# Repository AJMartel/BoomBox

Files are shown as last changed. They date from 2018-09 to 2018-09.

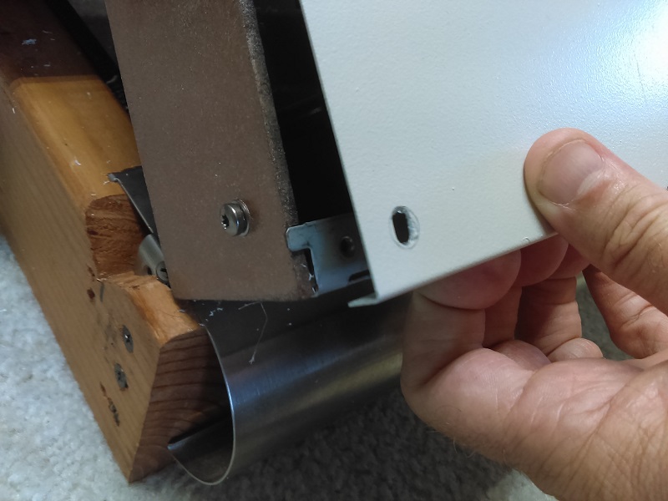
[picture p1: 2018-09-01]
IMAG0405.jpg

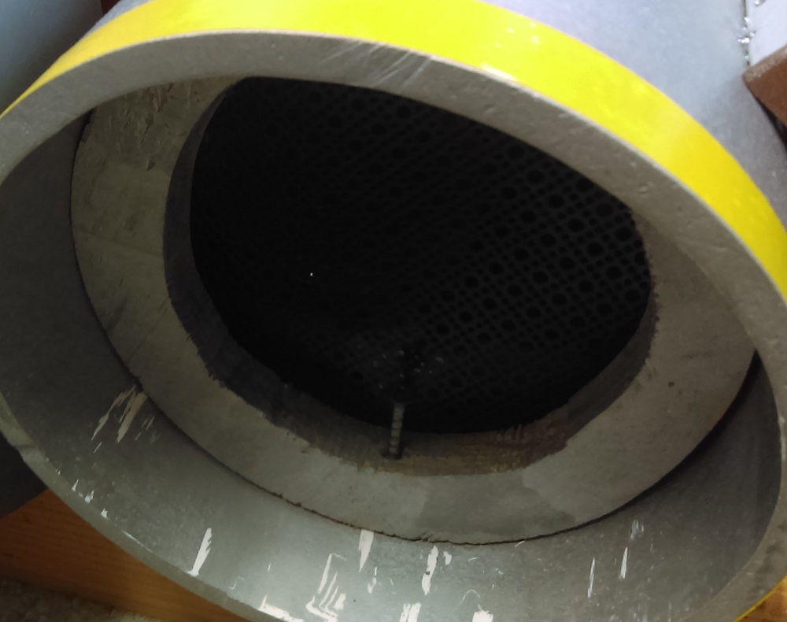
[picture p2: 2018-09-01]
IMAG0415.jpg

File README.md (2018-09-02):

# BoomBox
An airsoft game prop, featuring audio/mp3 capability, lighting, enhancement props, and bb air cannon.

There is no intent or schedule at this time to improve or build on this project, or make more versions. Its published here for a community share, more or less. I drew pretty heavily on posts and items others had shared when i built it, and thought i should give back.

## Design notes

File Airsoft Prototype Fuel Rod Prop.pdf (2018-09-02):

## Airsoft Prototype Fuel Rod Prop

The fuel rod prop is intended to assist airsoft games by adding a level of realism. It has 5 game modes, one demo mode and a sensitivity setting mode. The game mode is altered by simply tapping the device within 5 seconds of powering it up to step thru the modes.

It is a simple looking cylinder with 3 levels or RGB LED lights in the opaque center section. The main power switch is hidden in a pinhole and is a push-on/push-off style switch. The system takes input from a hidden internal magnetic switch in the rear of the base, and a shock sensing piezo. The system communicates its status using the RGB LEDs and a simple piezo beeper.

### Power

Power for the system is from an internal LiPo or NiMh (9.6v max power no matter what battery is used) battery connected with a deans connector. Changing the battery is as simple as unscrewing the lock screw and the end cap on the top of the device and switching out batteries.

### Setting a mode

Power on the device, using a pin or small metal rod to press the hidden power switch, then hold the device steady. The device will initialize and show the current mode. The mode is retained from the last setting automatically.

If you wish to change the mode, tap the device within 5 seconds of powering it on. Each tap will be reported by a change in the light display and the number of beeps corresponding to the mode. Since there is no other display, the RGB lights use binary to show the current mode (the top LED is bit 1, value of 1 - middle #2 LED is bit 2, Value of 2 - bottom #3 LED is bit 3, value of 4). You add up the lit lights to get the mode (mode 5 would be top and bottom or 1+4 lit up). Or just count the beeps.

### Charging Base

The unit uses a charging base with a hidden magnet to “charge” or “disarm” the device. The bases are not selective – all bases have the same effect, so it will be up to the players to follow rules about where they can charge and not “cheat”. However, players that figure out this fact may end up improving game play, so the enforcement of your rules on where and when a charge/discharge base can be used is entirely up to you.

One idea to enforce base restrictions is to mount the base on a removable stand, and place/remove the bases as needed for game play.

### Modes

The modes are as follows. More details about the mode are included below the table. Generally speaking, a blue unit is discharged and will not explode. A green unit is charged, and may or may not explode or discharge if shaken or the charge decays. Red is always danger. White indicates programming mode or what mode is selected.

Mode (binary) | Name | Details
1 (001) | Resupply Safe | Starts uncharged, so the players must find a base to charge it. After charged, the contents decay within 30 minutes. If a player

| | pushes the device into red mode by shaking it more than 5 times, the unit discharges.
2 (010) | Demo | Used in initial rally to show the players how the unit operates. Unit starts discharged, must be charged, then decays within one minute to “discharged” mode (blue). Unit can be recharged as many times as desired to demonstrate.
3 (011) | Sensitivity Set | Not a game mode. In this mode, the green LED blinks for 5 seconds waiting for you to “tap” the unit as hard as you want the shake sensor to be set. Hold the unit without shaking at all for maximum sensitivity, tap hard to make the unit robust. Hold unit still for 5 seconds to accept your setting after tapping.
4 (100) | Search & Rescue | Unit starts charged but “blinks” and beeps every 3 seconds to help locate it. Charge will decay within 30 minutes. The unit will go red if abused and pushed to red zone but will never explode or die from abuse. Game ends when charge totally decays, or they deliver it to a base and insert it to deliver the supplies.
5 (101) | Hot Potato | Unit starts charged. Pushing unit to red mode 5 times will cause it to explode. Unit will explode at the end of 30 minutes as well – UNLESS the base is used to reset the countdown.
6 (110) | Rush | Starts charged. Unit will react to shaking but will never be disabled. There is no decay, but the unit must be placed in a base for 5 minutes to explode. Unit resets after explosion.
7 (111) | Resupply Risky | Starts uncharged, so the players must find a base to charge it. After charged, the contents decay within 30 minutes. If a player pushes the device into red mode by shaking it more than 5 times, the unit explodes.

### Basic Diagram

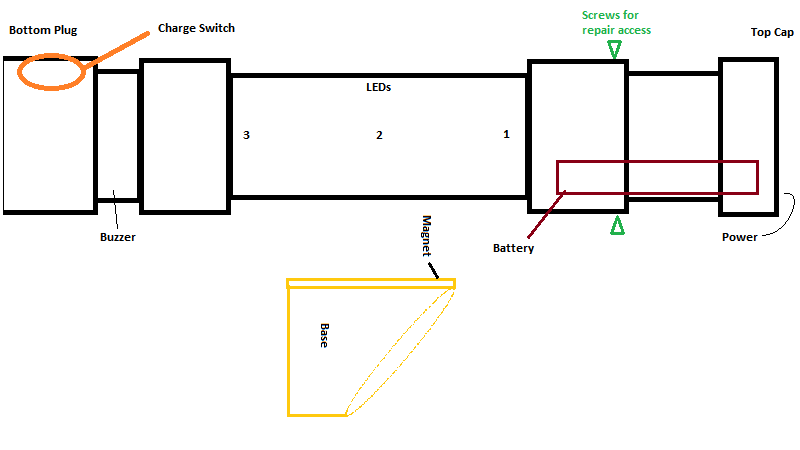
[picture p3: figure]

Cheat Sheet:

Mode (binary) | Name | Details
1 (001) | Resupply Safe | Uncharged, Charge decay 30m. 5Reds Discharges.
2 (010) | Demo | Used to demo unit. Starts discharged, once charged decays in 2 mins and shaking 2x makes it go red and discharge. Can be recharged.
3 (011) | Sensitivity Set | Unit blinks green for 5s listening for shake level (tap it how hard you want, not at all for max sense. Hold for 5s to accept level.
4 (100) | Search & Rescue | Blinks/beeps at start, picking it up starts 30m countdown to discharge. Charge decays in 30m. Insert in base to deliver and win.
5 (101) | Hot Potato | Charged. 5Reds to explode, or 30m countdown to explosion. Placing in base will reset countdown.
6 (110) | Rush | Charged, No shake reaction, no decay. Unit counts down 5m when placed in base to explosion, then resets.
7 (111) | Resupply Risky | Uncharged, Charge decay 30m. 5Reds Explodes.

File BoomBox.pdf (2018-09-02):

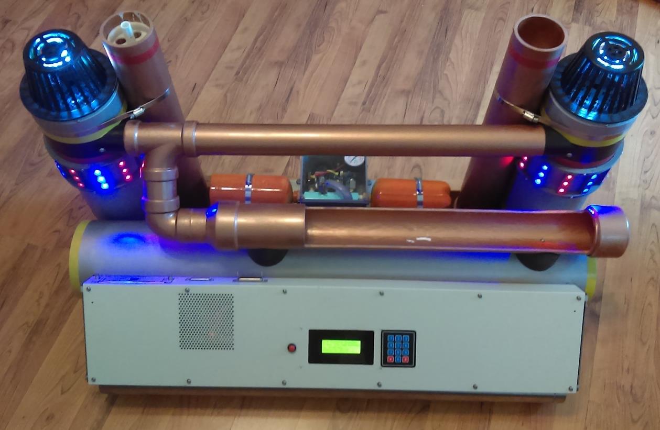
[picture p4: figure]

NOTICE – This *Manual* is part of a simulation designed for use by airsoft fields for entertainment and training purposes. No item described in this document is dangerous or life-threatening in the course of normal Airsoft Game Rules, and all organizations are fictitious. All trademarked names and logos and titles are owned by their respective copyright owners and all use is claimed as “fair use” for parody purposes.

# OPERATING MANUAL: BOOMBOX

DEVICE OVERVIEW

The following manual is intended for qualified personnel only. Operation and deployment of the BoomBox devices requires familiarity with the operating modes and options for maximum impact. Your effort in reviewing and practicing with the device, as well as anticipating how adept the players are at following the instructions, will be rewarded with smooth gameplay and maximum player involvement.

What follows is the operation and maintenance guide for this particular model: The BOOMBOX model.

CONTENTS

NORMAL OPERATION PROCEDURES

MODES OF OPERATION

The unit supports four modes of operation:

1. Simple Countdown Timer to Detonation
2. PIN code Lockdown to Detonation
3. Repeating Countdown to Detonation
4. Nuclear Fuel Charge and Countdown

Mode 4 assumes that a compatible Fuel Rod device is available. Modes can be altered or the device reset using the Initial Configuration process detailed below.

NOTE THAT IF A SYSTEM RESET IS NOT PERFORMED ON POWER-UP, THE LAST OPERATING MODE IS RE-STARTED.

STRONG RF EMISSIONS NEAR THE DEVICE HAVE BEEN PROVEN TO CAUSE UNDESIRED OPERATION, INCLUDING HANGING THE CONTROLLER, ERRONEOUS KEYPAD ENTRY, ETC. IT IS RECCOMMENDED THAT RF TRANSMITTERS ARE NOT OPERATED WITHIN SEVERAL FEET OF THE DEVICE.

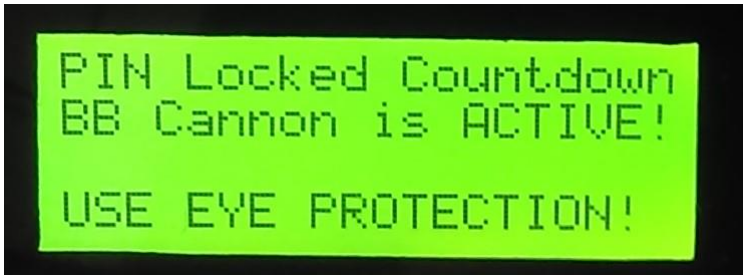
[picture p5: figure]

WARNING. IF THE BB CANNON IS ENABLED, THE SYSTEM WILL PLAY AN ALERT AT THE BEGINNING OF THE GAME. NO WARNING IS GIVEN BEFORE THE BB CANNON FIRES. THE COMPRESSOR WILL NOT RUN IF THE BB CANNON IS DISABLED HOWEVER, SO THAT IS THE BEST INDICATION DURING GAME PLAY THAT THE CANNON WILL FIRE UPON DETONATION. THE COMPRESSOR POWERS UP 30 SECONDS BEFORE DETONATION.

INITIAL CONFIGURATION/RECONFIGURATION

Initial configuration or altering the system settings is performed by accessing the programming menu. Since timing is critical, please read this section entirely before proceeding.

Follow these steps to initialize the device:

1. Obtain a thunder-B pin or other suitable small metal pin to use as the power key.
2. Note the position of the key access hole. Press a pin into the hole to turn the unit on and off.

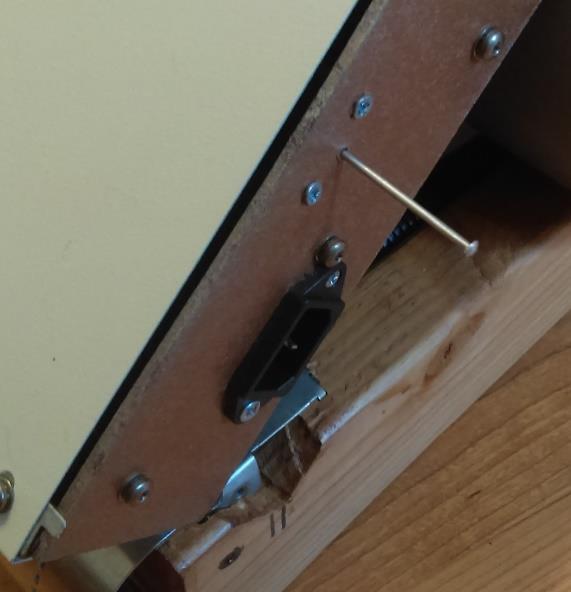
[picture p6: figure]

3. Once powered up, the system start initialization. Lights and audio effects will begin. Once the LCD initializes, important information will be displayed, including warnings about battery life. If no other option is chosen the device will immediately start the last configured game mode.
4. Immediately press and hold the red button to reset the device.
5. The device will reset the memory and allow you to select the mode of operation.

Preparing the BB Cannon is a simple matter of filling it with BBs from the top of the tube. It doesn’t matter if you fill the center or main fill holes around the center barrel, either will work. Not all BBs will be used in every shot, however the design is tolerant of some stray debris. Using ‘used’ bbs is permitted assuming they are not overly dirty. If the BB pressure setting needs to be adjusted the pressure switch can be adjusted by removing the cover and adjusting the screw (in means less pressure, 10-70PSI range). The duration of the pump power is controlled by the program and is not programmable.

PROGRAMMING MENU DETAILS

The following settings are available in Program Mode. Most of the features affect multiple game modes, but some have different effects depending on Game Mode. For example, EOD Mode allows guessing a PIN on PIN game, but in Fuel Charge mode it allows bypassing the detonation by simply holding a button. Details on modes and flow of the game is described in the game mode sections below.

1. Game Mode Selection:
a. Countdown Timer to Detonation
b. PIN code Lockdown to Detonation
c. Repeating Countdown to Detonation
d. Nuclear Fuel Charge and Countdown

2. Pre-Countdown Locate Beep: Prior to starting a countdown, the device can “beep” every 3 seconds to aid players in locating it. This mode allows you to hide the device on the field and help players find it easier.
3. Countdown Strobe: Enable or disable the strobe to flash every second during an active countdown.
4. Countdown Beep: Enable or disable the beeper to sound every second during an active countdown.
5. Countdown Time: Countdowns can run from 1 minute to 1000 minutes.
6. EOD Mode: Explosive Ordinance Disarming Expert Mode enable or disable. In PIN game, EOD means guessing a PIN will tell you high/low and never detonate from a bad PIN. In Nuclear Canister mode, the system can be disarmed by holding the red button for 2 minutes without interruption. Note that this mode is SEPARATE from the card/canister disable option.
7. Canister Sense: Allows using a suitable fuel rod to disarm the device instead of a card.
8. Card Sense: Enabling this mode allows a “hacking card” to immediately disable the device during countdown.
9. PIN: Enter a 1-9 digit PIN. If EOD mode is enabled, a 4 digit PIN should be used at the minimum.
10. Two Minute Warning: Enable this to hear the 2 minute klaxon sound and voice warning.
11. Two Minute Song: The MP3 song number to play as a two minute ambient music selection. MP3 song numbers can be found in the hidden MP3 Jukebox mode. (Ask)
12. Alert Duration: Number of seconds (1-240) that the alarm sounds when the device is detonated.
13. BB Cannon: Enable or Disable the BB Cannon when the device is detonated. Note that the compressor will also start ~30 seconds before end of countdown if BB Cannon is enabled.
14. MP3 Juke Box Mode: Set this to O to disable, or number of minutes between songs (5 or more suggested) if you want the device to randomly choose an MP3 song to play after being disabled or detonated.
15. Main Volume: Volume level (1-30) of most announcements. Warnings and effects may be louder than this level and cannot be adjusted. During MP3 play, the 7 and * keys allow volume up/down adjustments independent of the main volume setting.

FUEL ROD INTEGRATION NOTE

The Fuel Rod Prop suggested game play mode is any mode that uses the base to discharge the fuel rod. At the current time, that is:

- Mode 1 – Hot Potato
- Mode 5 – Search and Rescue

The fuel rods or canisters must have a strong magnet to trigger the sensor in the bottom left canister slot (over the left support). A small strong magnet is embedded in the bottom of the canister slot to trigger Fuel Rod sensors as well.

MODE 1 - SIMPLE COUNTDOWN TIMER TO DETONATION

Mode 1 allows the typical scenario – Once you start the countdown, it continues until the device detonates. You can pause the countdown by pressing the red button. You can also disable the device by using the card or fuel canister, if you have enabled those options.

Note that if you enable the card defeat or canister option, those devices must NOT be present or installed when the countdown starts (or it would immediately end). Of course, it is possible to put a dummy card or fuel rod in the device, which does not have the magnets installed, in order to allow normal operation.

EOD mode does not have any effect on this game mode.

GAME FLOW

The initial flow of this game, from system power on, is as follows:

1. System Powers up. Self-checks for battery level and other items are made, and warnings are played if the BB cannon is enabled.
2. Self-checks for cards or canisters are made if those options are enabled, and the system will wait until those are removed before proceeding.
3. The device will wait until a red button is pressed to begin the countdown. If the locator option is enabled, it will also beep once every 3 seconds to aid players in locating it. Once players start the countdown the locator will stop.
4. The device will count down to detonation:
a. If the two minute warning option is enabled, a two minute alert klaxon sound and voice will be heard just before 2 minutes.
b. If the two minute ambient music option is set to a song number other than 0, that song will be played. Recommendation is to play track 36, which ends exactly at 2 minutes.
c. If the BB Cannon is enabled, at 30 seconds the compressor will start up and pump up the chambers.
5. Detonation can be disabled by inserting a bypass “hacking” card, or inserting a canister, assuming those options are enabled in programming (card sense, and can sense).
6. The countdown can be “paused” by pressing the red button. Pressing the red button again restarts from the same point in the countdown.
7. At detonation the device will sound for the set alert period and stop.
8. After detonation, the device will wait the number of minutes (0 disables) and randomly play an MP3 file. Red button stops the song, 7 and * keys adjust volume up and down.

MODE 2 – PIN CODE LOCKDOWN TO DETONATION

Mode 2 allows the device to be locked down using a 1-9 digit PIN code. The device can be unlocked by entering the same code again.

NOTE – ENTERING AN INVALID PIN CODE 4 TIMES WILL INVOKE THE “ANTI-HACKING” MODE, CAUSING THE DEVICE TO DETONATE AND REMOVE SAID HACKERS.

EOD Mode allows an EOD expert to bypass the countdown by guessing the PIN code. In EOD mode, the system will allow unlimited PIN guesses without detonating. Each guess will trigger a “too high” or “too low” response, allowing the player to adjust their next guess. With a 4 digit PIN above 1000, this can take on average 2 minutes to guess.

Hitting the * key gives a -/+ 200 numbers range on the display. This quickly reduces the guessing time. Tell players about this hint if you wish.

Hacking cards and canisters will disable the system immediately if those options are enabled.

GAME FLOW

The initial flow of this game, from system power on, is as follows:

1. System Powers up. Self-checks for battery level and other items are made, and warnings are played if the BB cannon is enabled.
2. Self-checks for cards are made if those options are enabled, and the system will wait until those are removed before proceeding.
3. The device pauses and waits for the proper PIN code. The countdown will not start without the PIN code. (EOD guess mode is not enabled for the initial starting PIN.)
4. Once the PIN is entered the countdown begins. The countdown may be halted by one of the following methods:
a. Entering the PIN again pauses the countdown.
b. Guessing the PIN with EOD Mode enabled pauses the countdown.
c. Entering the wrong PIN 4 times WITHOUT EOD Mode detonates the device.
d. Inserting a “hacking card” with card sense enabled disables the device.
e. Inserting a fuel rod with “can sense” enabled disables the device.
5. If the device is disabled, the countdown cannot be restarted. If the device is paused using the correct PIN, the countdown may be continued by entering the correct PIN again.
6. The device will count down to detonation:
a. If the two minute warning option is enabled, a two minute alert klaxon sound and voice will be heard just before 2 minutes.
b. If the two minute ambient music option is set to a song number other than 0, that song will be played. Recommendation is to play track 36, which ends exactly at 2 minutes.
c. If the BB Cannon is enabled, at 30 seconds the compressor will start up and pump up the chambers.

7. At detonation the device will sound for the set alert period and stop.
8. After detonation, the device will wait the number of minutes (0 disables) and randomly play an MP3 file. Red button stops the song, 7 and * keys adjust volume up and down.

MODE 3 – REPEATING COUNTDOWN TO DETONATION

Mode 3 allows a somewhat modified scenario – Once you start the countdown, it continues until the device detonates and cannot be paused. You can “reset” the countdown by pressing the red button, which causes the countdown to restart from the beginning. You can also disable the device by using the card or fuel canister, if you have enabled those options. Without the disable card or canister, the device can never be disabled, and must constantly be reset to prevent detonation.

Note that if you enable the card defeat or canister option, those devices must NOT be present or installed when the countdown starts (or it would immediately end). Of course, it is possible to put a dummy card or fuel rod in the device, which does not have the magnets installed, in order to allow normal operation.

EOD mode does not have any effect on this game mode.

GAME FLOW

The initial flow of this game, from system power on, is as follows:

1. System Powers up. Self-checks for battery level and other items are made, and warnings are played if the BB cannon is enabled.
2. Self-checks for cards or canisters are made if those options are enabled, and the system will wait until those are removed before proceeding.
3. The device will wait until a red button is pressed to begin the countdown. If the locator option is enabled, it will also beep once every 3 seconds to aid players in locating it. Once players start the countdown the locator will stop.
4. The device will count down to detonation:
a. If the two minute warning option is enabled, a two minute alert klaxon sound and voice will be heard just before 2 minutes.
b. If the two minute ambient music option is set to a song number other than 0, that song will be played. Recommendation is to play track 36, which ends exactly at 2 minutes.
c. If the BB Cannon is enabled, at 30 seconds the compressor will start up and pump up the chambers.
5. Detonation can be disabled by inserting a bypass “hacking” card, or inserting a canister, assuming those options are enabled in programming (card sense, and can sense).
6. The countdown can be “reset” and forced to restart the countdown from the beginning by pressing the red button.
7. At detonation the device will sound for the set alert period and stop.

8. After detonation, the device will wait the number of minutes (0 disables) and randomly play an MP3 file. Red button stops the song, 7 and * keys adjust volume up and down.

MODE 4 – NUCLEAR FUEL CHARGE AND COUNTDOWN

This mode allows the charging and arming of the device using a suitable Nuclear Fuel Rod/canister. You should start this mode with the canister REMOVED. You can give the canister to the players or make them find it. Once the nuclear fuel charge is loaded, a countdown begins. The countdown can be cancelled by attaching a suitable canister and transferring the charge back.

NOTE – THE FUEL ROD CANISTER MUST HAVE THE REQUIRED MAGNETS AND COMPONENTS IN ORDER TO WORK WITH THIS MODE. JUST ANY CYLINDER WILL NOT WORK!

EOD Mode allows an EOD expert to bypass the countdown by holding the red button for 4 minutes.

Canisters will not “disable” the system countdown immediately, but are used in a “discharge” sequence and end up disabling the countdown eventually. Hacking cards will disable the system immediately if that option is enabled.

GAME FLOW

The initial flow of this game, from system power on, is as follows:

1. System Powers up. Self-checks for battery level and other items are made, and warnings are played if the BB cannon is enabled.
2. Self-checks for cards are made if those options are enabled, and the system will wait until those are removed before proceeding.
3. The canister must be removed from the device and the red button pressed to set the unit up for game play. THIS IS DONE BY THE ADMIN. Once this is done, the device is ready to accept a canister from a player to start the arming sequence. You don’t have to have the canister to start this mode, but if you do, and it’s present on the device, you do have to remove it to start the game mode.
4. The device asks the player to insert the canister, which starts the prime process. This process takes 10 seconds.
5. The device asks the player to hold the red button to charge the device. This takes 10 seconds.
6. The device asks the player to remove the canister to start the countdown.
7. Once removed, the countdown starts.
8. The device will count down to detonation:
a. If the two minute warning option is enabled, a two minute alert klaxon sound and voice will be heard just before 2 minutes.
b. If the two minute ambient music option is set to a song number other than 0, that song will be played. Recommendation is to play track 36, which ends exactly at 2 minutes.

c. If the BB Cannon is enabled, at 30 seconds the compressor will start up and pump up the chambers.
9. Detonation can be disabled by inserting a bypass “hacking” card (card sense must be enabled), or inserting a canister and following the discharge process. EOD mode allows disabling the device by holding the red button for 4 minutes continuously.
10. If the EOD mode is not enabled, and the red button is pressed in an attempt to bypass the device but a fuel rod is NOT present, a hacking attempt is triggered and an accelerated countdown begins.
11. At detonation the device will sound for the set alert period and stop.
12. After detonation, the device will wait the number of minutes (0 disables) and randomly play an MP3 file. Red button stops the song, 7 and * keys adjust volume up and down.

SYSTEM MAINTENANCE

OVERVIEW

System maintenance includes items such as pre-operation checks, battery charging and replacement, and fuse replacement. The system is generally built to handle normal use but any time the device is dropped, kicked or knocked over, an inspection of the internal connections and components should be performed.

Modifying the code operation – aside from the configuration options in the programming menu – is not covered in this manual. The unit uses C++ Arduino style programming language with a Teensy 3.2 LC controller and a DFRobot MP3 player device, and does support direct USB connections for reprogramming. Please contact the D14 owners for questions about the program source code or design documentation.

TROUBLESHOOTING STRANGE BEHAVIOR

Note that if a program mode is NOT performed on power-up, the last operating mode is re-started.

Strong RF emissions near the device have been proven to cause undesired operation, including hanging the controller, erroneous keypad entry, etc. It is recommended that RF transmitters are NOT operated within several feet of the device.

If the device display becomes garbled or appears to hang, power the system down with the access key, then power it back on. The last program will be restarted.

If the strobes or air horn devices sound continuously, the MOSFET devices may have failed. MOSFET devices typically (eventually) fail as a short circuit. Turn off the controller with the key switch, and remove the right access panel to access the main system fuses, or disconnect the battery from the control or compressor or other components. Pulling fuses is recommended.

In the event of continuous air horn operation, use hearing protection when trying to disable the system. Do not attempt to disable to compressor or horns directly, rather, remove power from the compressor by disabling main power or removing the fuse.

OPENING THE CASE

The case should be opened using the round screen panel on the right side of the main tube body (when facing the keypad). Phillips head screws can be unscrewed half-way and the cover removed. Once that is accomplished, the internal component board can be pulled out to the right for service.

Note that to reinstall the main power board, you must also remove the left cover and guide the power board into the correct position, under the holding tab.

ALWAYS DISCONNECT ONE OR BOTH OF THE MAIN BATTERY CONNECTORS WHEN PERFORMING SERVICE.

MOSFETS AND SEVERAL COMPONENTS ARE ‘GROUND-SWITCHED’. WHICH MEANS THEY RECEIVE CONSTANT POWER FROM THE BATTERY + RAIL, AND GROUND IS SWITCHED BY THE MOSFET DEVICES. THIS MEANS THE MOSFET TABS AND HEAT-SINKS WILL NORMALLY BE RESTING AT +12VDC DURING OPERATION.

ACCESSING THE POWER BOARD COMPONENTS

1. Using a phillips screw driver, unscrew the 3 screws on the right tube cover. If you only unscrew them half-way you should be able to use them to pull the cover out.
2. Remove the cover, exposing the internal carrier board and connectors. Space is tight, so use a flashlight to look into the tube and slide the board out, rotating if needed to clear the cable feeds coming in the top of the tube. Gently slide out the borad half-way, then unplug the connectors if you intend to completely remove it. If you only need fuse access you don’t need to slide it out further. If you need to change the battery you should remove the entire board.
3. Details on the internal components and a component list is available in the specifications section of this document.
4. Reinstalling the board requires you to remove the left cover. Slide the board thru the tube until it reaches the tang that holds it down on the left. Move the metal tang around until it will slide over the board.
5. Push the board in the rest of the way until it bottoms out on the left holder. The board should be level, resting on the screw on the left (prevents it from rotating counterclockwise).
6. Push the right cover in and drive the screw in thru the tube and into the mounting wood base.

ACCESSING THE CONTROL PANEL INTERIOR

1. Using a suitable Torx bit, unscrew the 12 screws on the top and bottom of the front cover.

2. Remove the card from the top left of the control box.

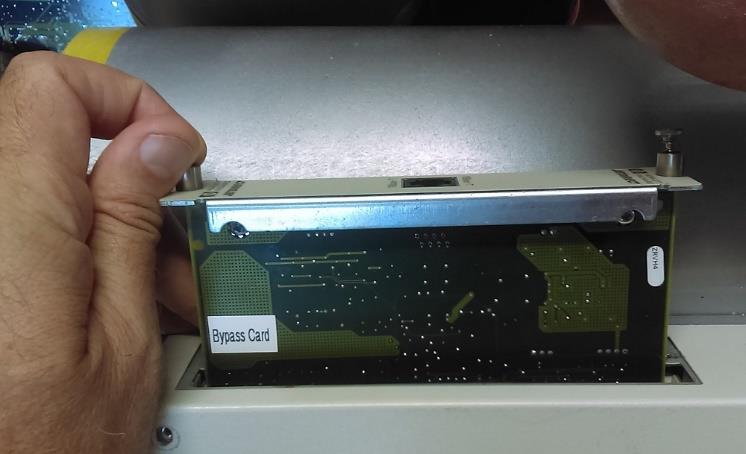
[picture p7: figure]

3. From the bottom, gently lift the front cover up:

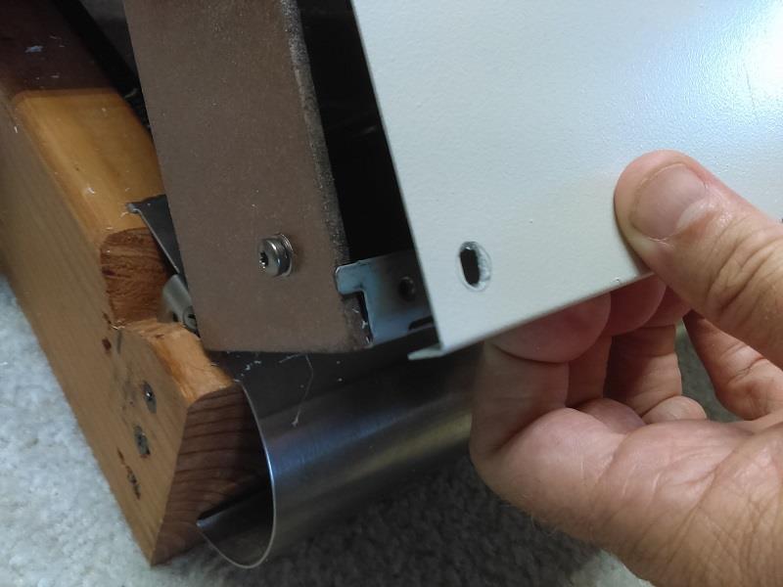
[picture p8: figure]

4. Slide the cover up to clear the connectors on top of the box, but DO NOT move the cover too far away from the unit, as you need to disconnect the LCD button and keypad.

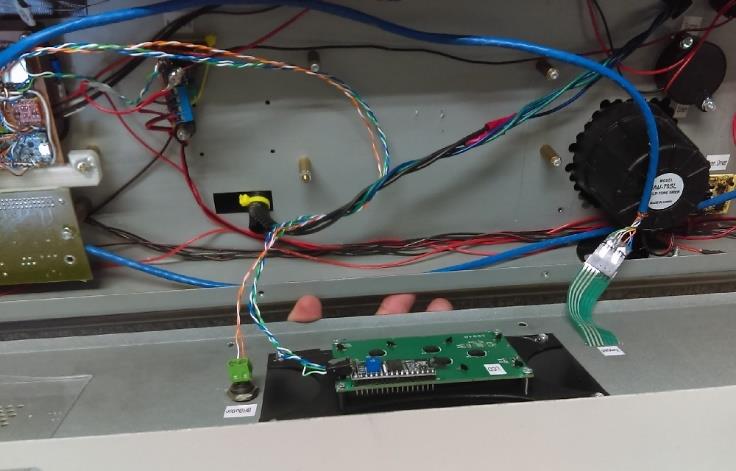
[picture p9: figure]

5. It is possible to rest the cover against the front of the unit without disconnecting cables.

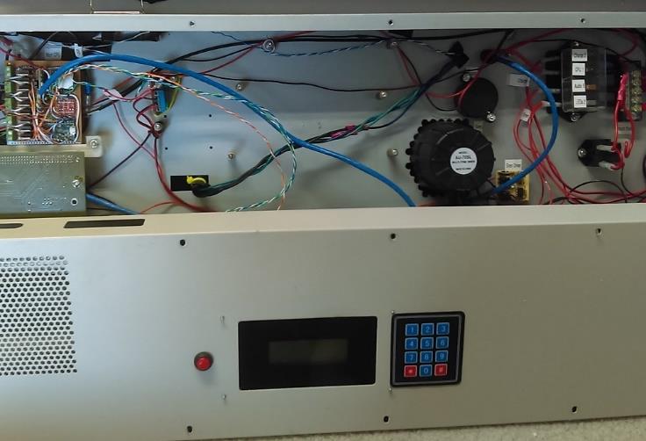
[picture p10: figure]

6. Details on the internal components and a component list is available in the specifications section of this document.

BATTERY CHARGING

Connect a business power cord to the right end of the control box, and plus the other end into a typical 120VAC US outlet. The on-board SLA battery charger may take several hours due to battery capacity (it is a larger 8A-Hr SLA). Battery is considered charged when the voltage reaches 13.6 VDC. Battery voltage less than 10.5V is not recommended and can damage the SLA battery.

NOTE – THE INTERNAL CHARGER IS INTELLIGENT, AND WILL SWITCH TO FLOAT MODE AUTOMATICALLY. THE DEVICE CAN BE LEFT PLUGGED IN INDEFINITELY WITHOUT CAUSING BATTERY DAMAGE.

Any white crusty residue on the “top” of the battery, or swelling of the battery indicates internal failure and requires the battery to be disposed of immediately. A Sulphur or rotten-egg smell also indicates overcharging and possible battery damage.

BATTERY REPLACEMENT

As this unit uses a Sealed Lead Acid Battery (SLA), please replace the battery with a suitable sized replacement. SLA batteries can be mounted in any position. The existing cell is a 7 or 8 Amp-Hour 12V battery. Power is marked as Red for +12V, and black for Ground.

Unscrew the bracket holding the battery down and one or more of the side screws to free the battery. When tightening the new battery down, ensure there is a very small amount of “wiggle-room” so the plastic battery case is not being crimped. Overtightening can crack the new battery case.

This is a standard battery design, and any battery with similar specifications can be used – whether it was sold for UPS, deer-feeder, telecom, or general use.

As the battery uses lead, proper disposal should be performed. Do not discard the battery in normal trash. Dispose of or recycle according to local ordinances.

FUSE REPLACEMENT

Fuses should not typically blow unless an internal short develops in the device or a component. Before replacing a fuse, investigate the component that blew the fuse and verify it is not malfunctioning. If the main 30A fuse blows, disconnect all other fuses (and keep track of which wires go with which fuse) and reconnect components one fuse at a time to isolate the cause.

Component | Fuse Size | Purpose
Main Battery 30 | 30A | Main power for all systems.
Air Horn 25 | 25A | Power for the Air Horn compressor (high current!)
Compressor 7.5 | 7.5 | Power for the air compressor for BB Cannon.
Valve/Relay 5 | 5A | Power for the Air valve and Relays.
Smoke 10 | 10A | Power for an optional component, originally intended for Smoke.
Control Box 10 | 10A | Power for the microcontroller, display, LED, Sound.
Charge 2 | 2A | Safety fuse for the power from the battery charger, to the power board.
CPU1 | 1A | Power for the Arduino and MP3 device board.
Audio5 | 5A | Power for the Audio Amp.
LEDs2 | 2A | Power for LED Strobe lights.

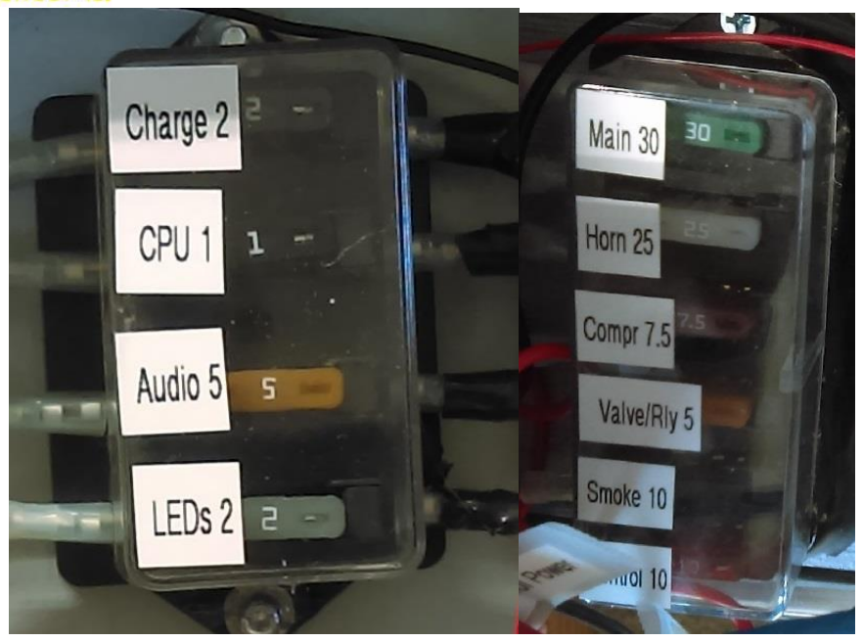
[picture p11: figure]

AUXILLARY INFORMATION/SPECIFICATIONS

INTERNAL COMPONENT LIST

The following components are used in this device.

Component

Main Battery. SLA 12VDC 7 or 8 AHr battery. (UB1280 or similar) 30A Main fuse on battery.

Power board Fused power connection block. Most high power component fuses are located here.

Ground Distribution bank. Used to ground various parts of the system.

Relay bank. Clamping Diode installed across coils of each relay. If you replace this device use a suitable clamping diode to shunt spikes and connect with correct polarity. Relay is 30A, 30VDC rated. 12V coil. Relays are labeled for purpose. Equipment is ground switched or positive switched depending on system. Relay coils are ground switched.

Air horn compressor. Loud on its own, bolted to the carrier board. Uses a 20A fuse. No maintenance possible on this part.

Air Horns. Dual low frequency horns, zip-tied for convenient removal/replacement.

Deans connectors – connecting compressor, main control box power, and main power.

Cat5 Network connection. Used to run relay control wires from control board.

Keypad/Control box. Teensy 3.2 LC controller with custom program, keypad and LCD I2C interface, MP3 serial interface and power regulation as well as control MOSFET switches are located on the control board to the left. On-board MP3 player uses a micro SD card to store sounds and audio. MP3 amplifier is near main control board. Siren driver board is next to the siren. Beeper is above the siren. Control system fuses and 120VAC battery charger. Main power switch turns on the 30A relay in the control box to power up control electronics and LED/audio.

LCD display – I2C connected to CPU board, blue, 4x20characters.

“Red Button” – main button used to arm/disarm/enter reset mode. Hold this button when powering system up to reset the device.

Power Switch. Switches power to control box only – however this will generally turn off all components. The charger will operate regardless of system power switch state.

Keypad – a standard 3x4 numeric keypad.

LED rings – Blue and RED alternating LED displays.

Speaker tubes – Speakers are outdoor rated and waterproof but may not survive if water is left standing on the speakers. If rain is encountered, cover the unit and tilt over to ensure no water collects in speakers or tubes.

White LED strobes – located above speakers.

BB Cannon tube – a simple air powered device. Air fires from the bottom bb reservoir across a small gap into the main tube. BBs are sucked up into the air flow and out the unit. Any BBs can be used, as long as they are not too dirty.

Air Valve – a sprinkler valve located under the unit to release air on command by the CPU.

Compressor box – houses a small 12VDC car compressor, limit switch (50PSI) and safety valve plus a gauge. Do not block the inlet or outlet near tanks.

Air tanks – repurposed propane tanks (cleaned), with no neck valves. Tank safety valve is retained but should never be used as the safety limit valve is set to a much lower 100PSI level and should always release first.

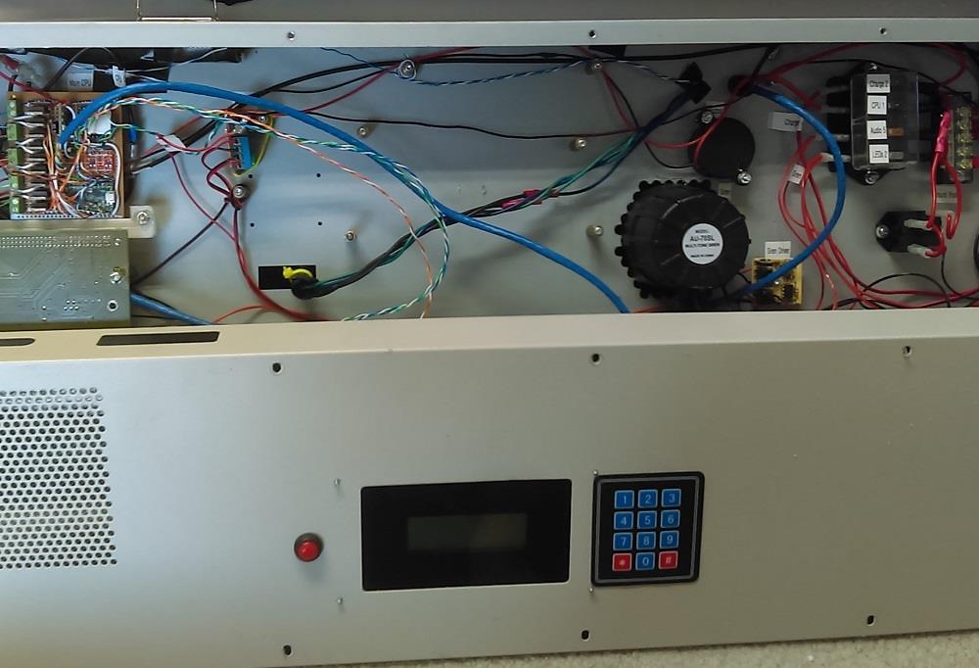
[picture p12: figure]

Internal Components: Control Box:

Main CPU Board

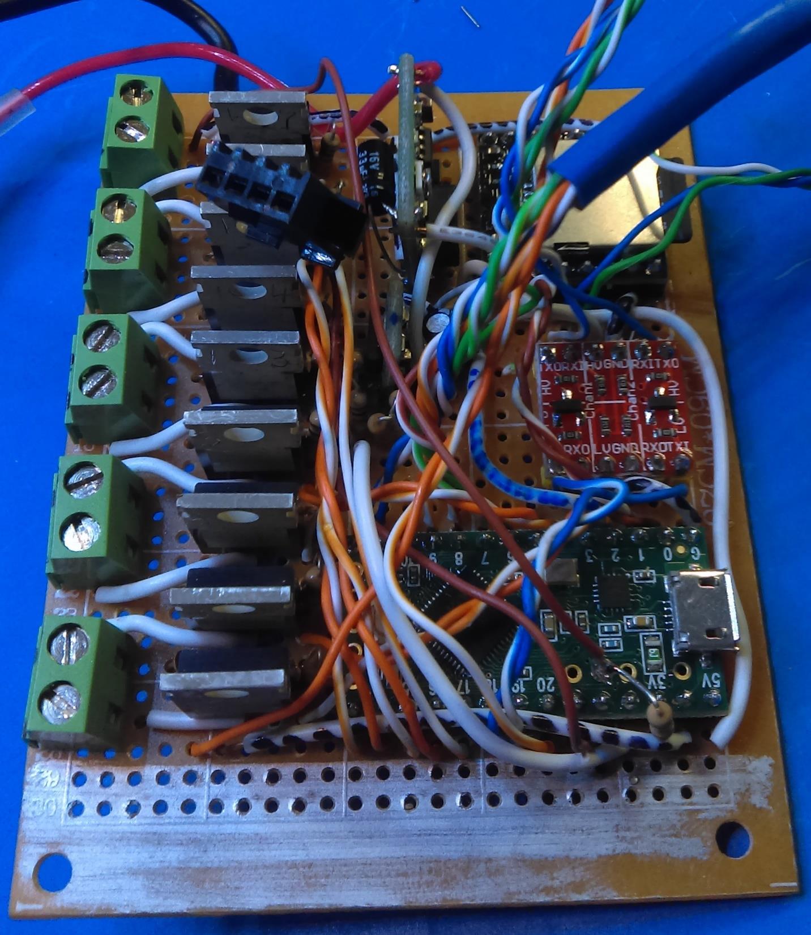
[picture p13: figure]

Mai n
Main CPU board, with Teensy 3.2 LC at the bottom, level adapter above that, MP3 DF Robot board (with SD Card) above that. The center contains a 5V regulator (do not adjust!) and 3.3v regulator board, both mounted on end. The left side contains 9 channels of MOSFET drivers with screw down terminals. Cables run to can and card sense connectors, BRB connections, LCD connections, MP3 connections and Keypad connections as well as power and ground. Since the unit switches ground to devices, the ground lead is much larger than the power lead.

Compressor Box:

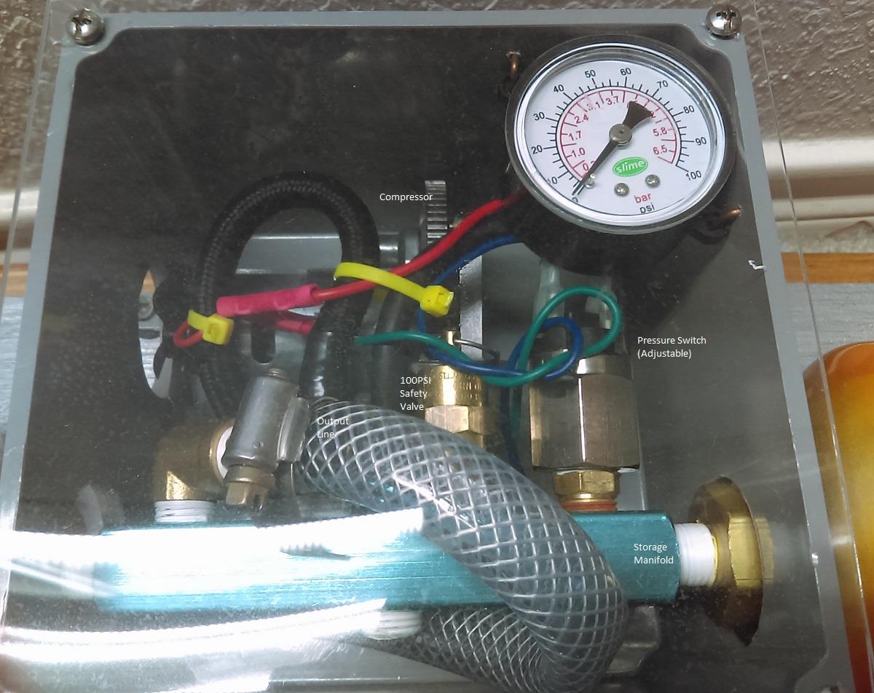
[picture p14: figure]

Compressor, Pressure Switch (50PSI setting, adjustable), safety valve (100PSI), gauge, manifold to tanks. Tanks are cleaned recycled Propane canisters, so some odor is present (it is not dangerous). There is also a sprinkler valve under the main tube and pipe to the (left) bb Cannon tube.

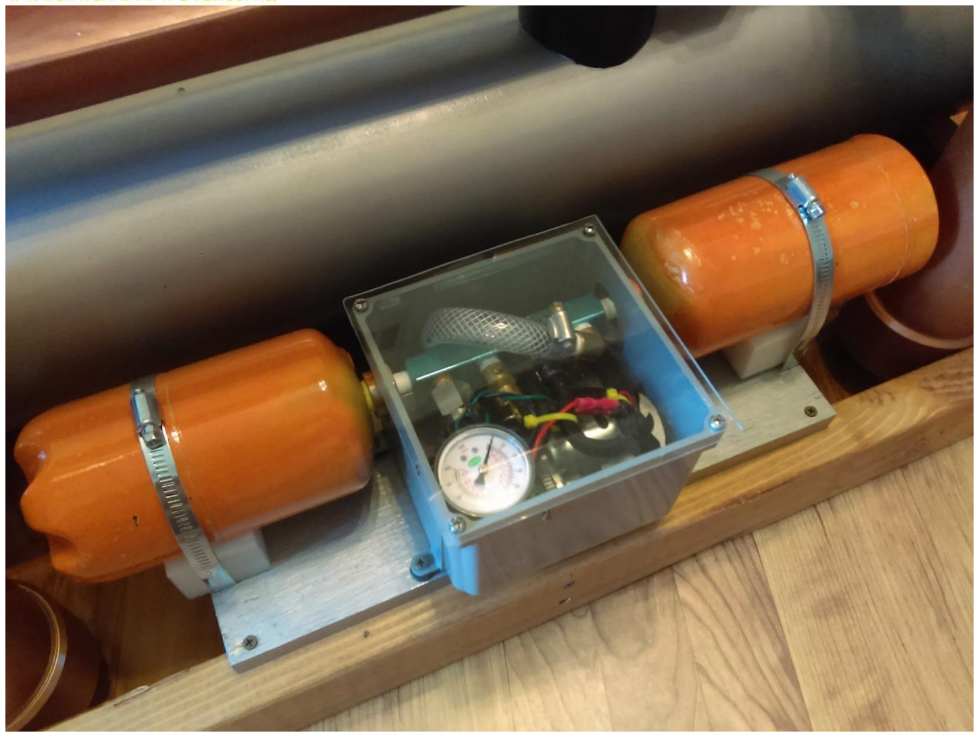
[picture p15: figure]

Power Board: Fuses and Relays

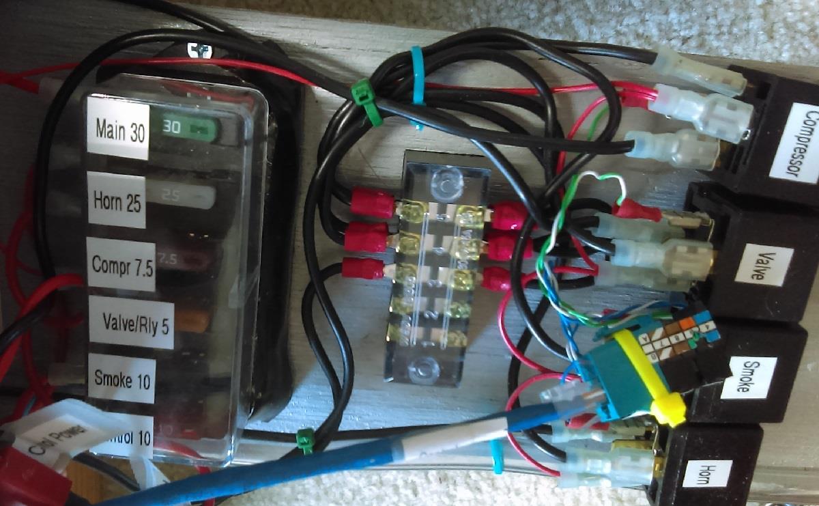
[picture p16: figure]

Fuses for major systems, ground supply block, relay bank and control cable connection are shown.

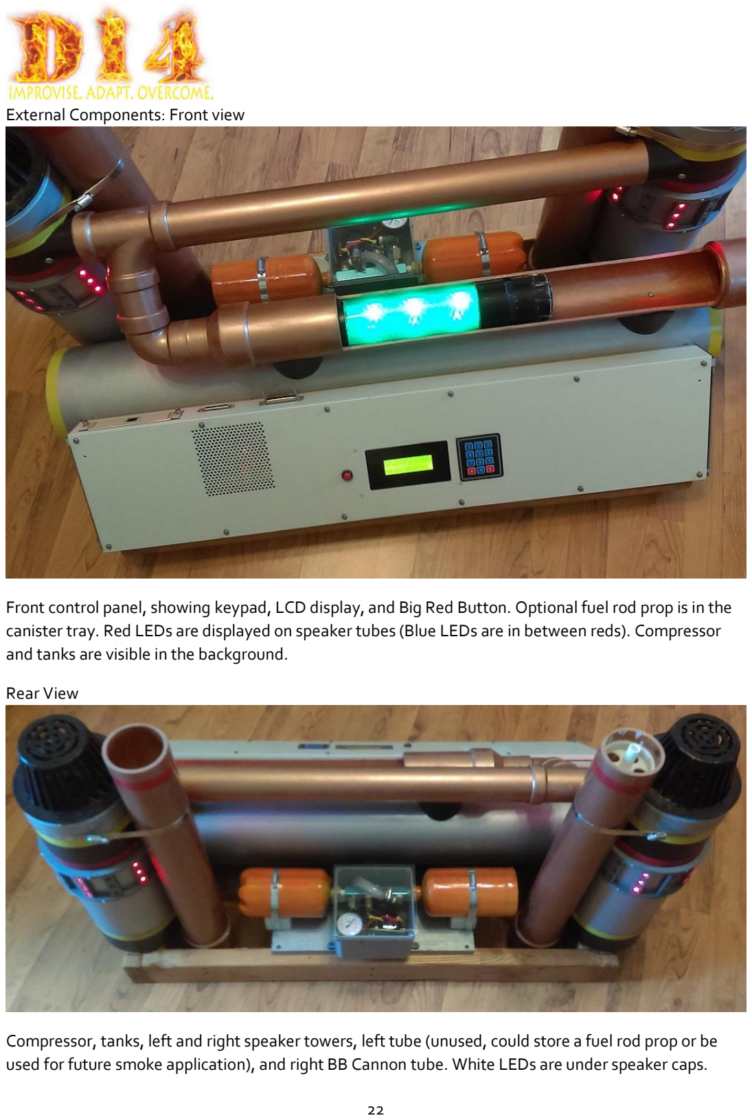
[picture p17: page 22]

External Components: Front view

Front control panel, showing keypad, LCD display, and Big Red Button. Optional fuel rod prop is in the canister tray. Red LEDs are displayed on speaker tubes (Blue LEDs are in between reds). Compressor and tanks are visible in the background.

Rear View

Compressor, tanks, left and right speaker towers, left tube (unused, could store a fuel rod prop or be used for future smoke application), and right BB Cannon tube. White LEDs are under speaker caps.

Miscellaneous Specs:

Weight: 28 Kg or 62 lbs.

Width: 1.17M 46 in.

Depth: 0.56M or 22 in.

Height: 0.69M or 27 in.

Power Supply: Internal 12VDC SLA battery, 7AHr.

Power Draw: Detonated – 23A Max, intermittent. 1A Idle. 2A countdown w/strobes, intermittent.

Theoretical Battery Life – 8Ahr/(1A average)=8 hours? Exact time estimates depend heavily on options chosen and volume of MP3 audio system.
Date of Creation: August 31st, 2016.

Paint Codes: RUST-OLEUM Hammered spray paints, Silver 7213, Copper 210849

Teensy LC Pinout:

Pin | Mode | Description
RX1,TX1 | Dig I/O | MP3 (DFRobot) Serial control.
D2 | Dig Out | Siren Out to MOSFET.
D3 | Dig Out | Compressor Out to MOSFET.
D4 | Dig Out | Air Valve Out to MOSFET.
D5 | Dig Out | Buzzer Out to MOSFET.
D6-D12 | Dig In | Keypad input Pin6-9: R1-R4, Pin 10-12: C1-C3
D13 | Dig Out | RED LED Out to MOSFET.
D14 | Dig Out | BLUE LED Out to MOSFET.
D15 | Dig Out | WHITE LED Out to MOSFET.
D16 | Dig Out | Smoke Out to MOSFET. (not enabled, for expansion)
D17 | Dig Out | Air Horns Out to MOSFET.
SDA0, SCL0 | Dig I/O | 3.3v I2C to level shifter, to LCD.
D20 | Dig In | Big Red Button input.
D22 | Dig In | Canister/Fuel Rod sense input.
A9 | Analog In | Battery Volt Sense, through divider (6.8K over 1.2K).
D24 | Dig In | Card sense input.

Fuel Rod/Canister modification: The fuel rods or canisters must have a strong magnet to trigger the sensor in the bottom left canister slot (over the left support). A small strong magnet is embedded in the bottom of the canister slot to trigger Fuel Rod sensors as well.

Schematic:

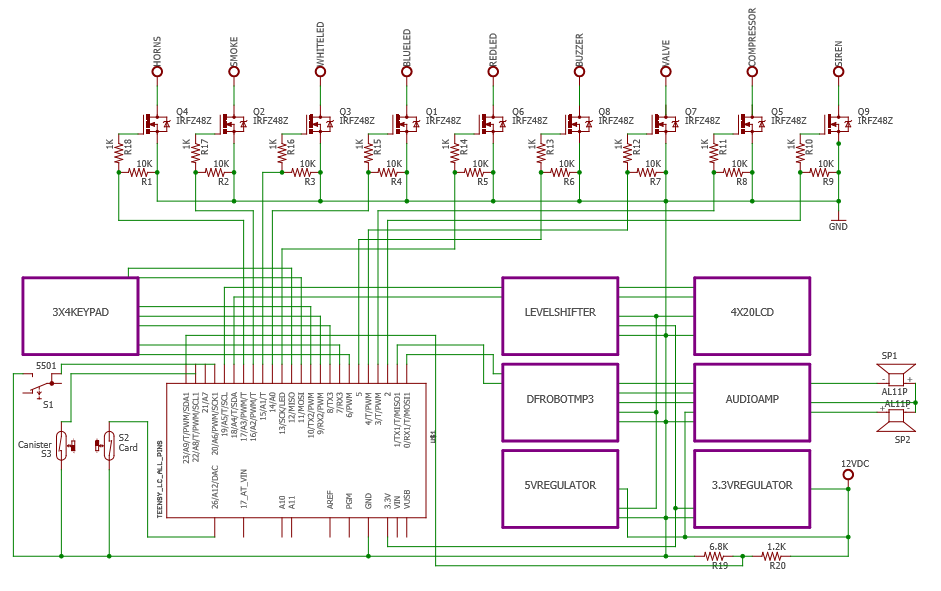
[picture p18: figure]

QUICK REFERENCE SHEET

Print copies of the following sheet for in-field reference.

Program Mode: Hold red button while turning device on with key switch. Wait for “Programming Mode” to be displayed or announced before releasing button.

Program Selection: The following program options are available.

1. Game Mode Selection:
a. Countdown Timer to Detonation
b. PIN code Lockdown to Detonation
c. Repeating Countdown to Detonation
d. Nuclear Fuel Charge and Countdown
2. Pre-Countdown Locate Beep: Prior to starting a countdown, the device can “beep” every 3 seconds to aid players in locating it. This mode allows you to hide the device on the field and help players find it easier.
3. Countdown Strobe: Enable or disable the strobe to flash every second during an active countdown.
4. Countdown Beep: Enable or disable the beeper to sound every second during an active countdown.
5. Countdown Time: Countdowns can run from 1 minute to 1000 minutes.
6. EOD Mode: Explosive Ordinance Disarming Expert Mode enable or disable. In PIN game, EOD means guessing a PIN will tell you high/low and never detonate from a bad PIN. In Nuclear Canister mode, the system can be disarmed by holding the red button for 2 minutes without interruption. Note that this mode is SEPARATE from the card disable option.
7. Canister Sense: Allows using a suitable fuel rod to disarm the device instead of a card.
8. Card Sense: Enabling this mode allows a “hacking card” to immediately disable the device during countdown.
9. PIN: Enter a 1-9 digit PIN. If EOD mode is enabled, a 4 digit PIN should be used at the minimum.
10. Two Minute Warning: Enable this to hear the 2 minute klaxon sound and voice warning.
11. Two Minute Song: The MP3 song number to play as a two minute ambient music selection. MP3 song numbers can be found in the hidden MP3 Jukebox mode. (Ask)
12. Alert Duration: Number of seconds (1-240) that the alarm sounds when the device is detonated.
13. BB Cannon: Enable or Disable the BB Cannon when the device is detonated. Note that the compressor will also start ~30 seconds before end of countdown if BB Cannon is enabled.
14. MP3 Juke Box Mode: Set this to O to disable, or number of minutes between songs (5 or more suggested) if you want the device to randomly choose an MP3 song to play after being disabled or detonated.
15. Main Volume: Volume level (1-30) of most announcements. Warnings and effects may be louder than this level and cannot be adjusted. During MP3 play, the 7 and * keys allow volume up/down adjustments independent of the main volume setting.

DISCLAIMER AND WARNINGS

This device is designed to enhance game play in an Airsoft scenario game. It is not dangerous or life threatening, assuming normal Airsoft game play rules are followed. Following typical rules, especially eye protection, when the BB Cannon is enabled should protect players from injury. The device is not intended to be moved during game play, especially by less than 2 people. Always instruct players to keep clear of the BB Cannon at all times, regardless of whether the system is powered or armed. When not in use, cover the cannon to prevent debris from entering or protect if accidental discharge occurs.

While it should be readily apparent to anyone this is a prop, based on design, it is still prudent to cover and conceal the device from general public view when not in use on the playing field.

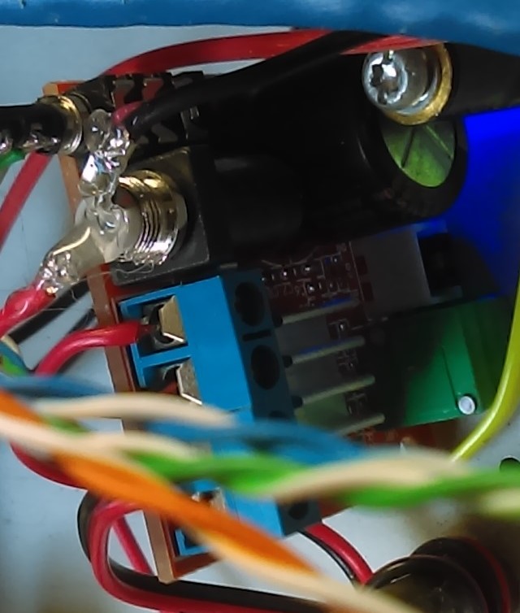
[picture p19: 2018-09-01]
IMAG0412.jpg

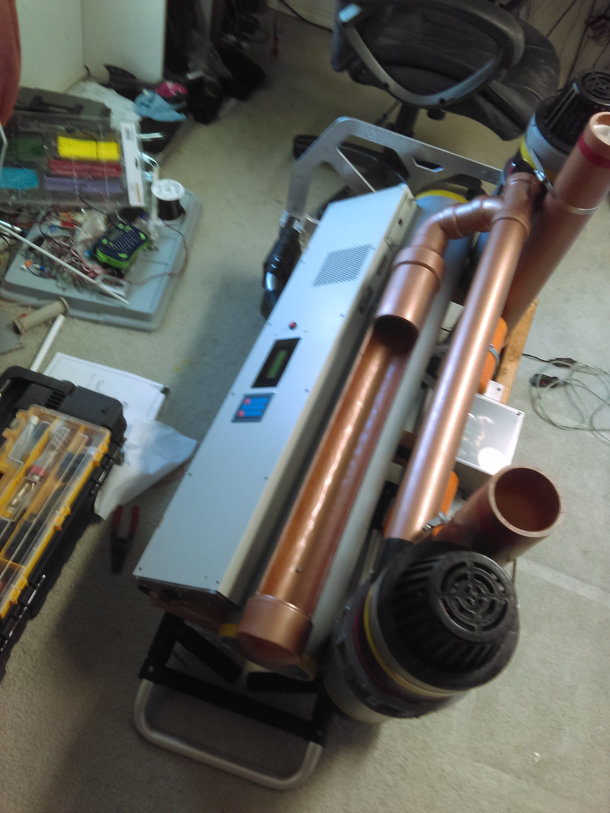
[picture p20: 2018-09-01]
IMAG0398.jpg

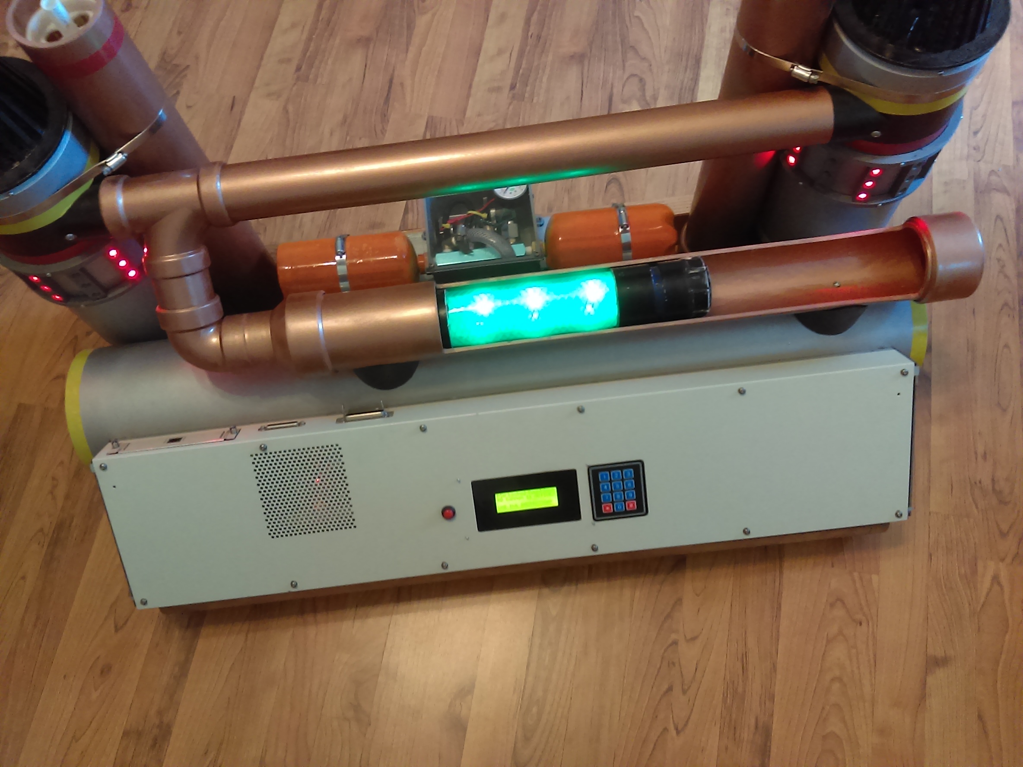
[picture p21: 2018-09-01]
IMAG0432.jpg

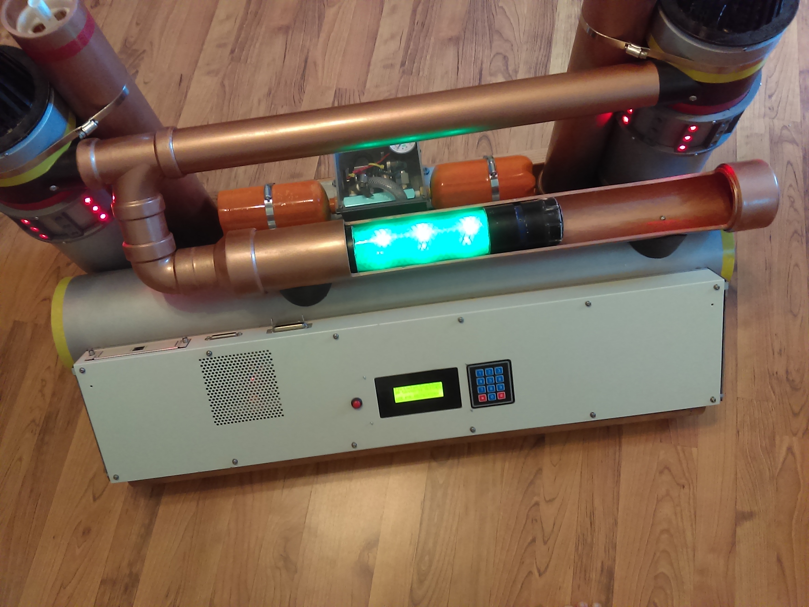
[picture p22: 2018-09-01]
IMAG0434.jpg

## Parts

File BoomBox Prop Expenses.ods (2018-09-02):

Item | SubComponent | Base Price | Qty | Amount | Taxable | With Tax | Tax Rate
3D Printed LCD Holder | Control Box | $- | 1 | $- |  | $- | $0.08
All external wood treated or painted. | Appearance | $- |  | $- |  | $- | $0.08
All PVC externals sanded and painted and routed for joints to appear smoother. | Appearance | $- |  | $- |  | $- | $0.08
All wire connectios soldered and shrunk or crimped, if not part of a connector. | Misc | $- |  | $- |  | $- | $0.08
Code Dev Time-Hours (actual * .3 factor for my non-expert skills? No idea what value is...) | Code | $- | 40 | $- |  | $- | $0.08
Code for Fuel Rod (added BoomBox Mode) | Control Box | $- |  | $- |  | $- | $0.08
Documentation. | Code | $- |  | $- |  | $- | $0.08
Misc Paint (Orange, Black, Hammered Copper, Silver) | Appearance | $- | 1 | $- |  | $- | $0.08
SamCobalt Bar Magnets (Fuel Rod Mod) | Control Box | $0.25 | 1 | $0.25 |  | $0.25 | $0.08
1x4"x4' Plywood mounting board | Power Board | $0.50 | 1 | $0.50 |  | $0.50 | $0.08
Reed Switch (Canister Sense) | Control Box | $0.50 | 1 | $0.50 |  | $0.50 | $0.08
SamCobalt Round Magnets (Fuel Rod Trip) | Control Box | $0.25 | 3 | $0.75 |  | $0.75 | $0.08
1/2 NPT Plugs | BB Shower | $0.90 | 1 | $0.90 |  | $0.90 | $0.08
Heat Shrink (1/2*2in, 1/4*4in) | Misc | $0.25 | 4 | $1.00 |  | $1.00 | $0.08
Solder | Misc | $1.00 | 1 | $1.00 |  | $1.00 | $0.08
3/4 to 1/2 Barb right angles | BB Shower | $1.20 | 1 | $1.20 |  | $1.20 | $0.08
Crimps | Misc | $0.12 | 10 | $1.23 |  | $1.23 | $0.08
TTL Level Converter | Control Box | $1.67 | 1 | $1.67 |  | $1.67 | $0.08
5V (adjustable) regulator | Control Box | $1.82 | 1 | $1.82 |  | $1.82 | $0.08
3D Print power adapter | Control Box | $2.00 | 1 | $2.00 |  | $2.00 | $0.08
3D printer tank holders | BB Shower | $1.00 | 2 | $2.00 |  | $2.00 | $0.08
End cap covers (circle wood) | Power Board | $1.00 | 2 | $2.00 |  | $2.00 | $0.08
End cap covers (rect wood) | Control Box | $1.00 | 2 | $2.00 |  | $2.00 | $0.08
Split Loom (6 ft of 18) | Appearance | $6.20 | 0.3 | $1.86 | 1 | $2.01 | $0.08
PEX tube | BB Shower | $1.86 | 1 | $1.86 | 1 | $2.01 | $0.08
Silicone Black | Audio System | $3.94 | 0.5 | $1.97 | 1 | $2.13 | $0.08
White LED Module | Audio System | $1.00 | 2 | $2.00 | 1 | $2.17 | $0.08
Cantex 4x4x2 box | BB Cannon | $6.88 | 0.3 | $2.06 | 1 | $2.23 | $0.08
10 ga Solid Wire ($/ft) | Power Board, Control Box | $0.20 | 12 | $2.40 |  | $2.40 | $0.08
Perfboard | Control Box | $2.49 | 1 | $2.49 |  | $2.49 | $0.08
3D Printed BB Canon Parts | BB Cannon | $5.00 | 0.5 | $2.50 |  | $2.50 | $0.08
Zip Ties | Misc | $0.10 | 25 | $2.50 |  | $2.50 | $0.08
Manifold | BB Cannon | $5.37 | 0.5 | $2.69 |  | $2.69 | $0.08
2x4x12 | Appearance | $2.65 | 1 | $2.65 | 1 | $2.87 | $0.08
Keypad | Control Box | $2.99 | 1 | $2.99 |  | $2.99 | $0.08
PC-XT power plug/socket (2pack) | Control Box | $5.98 | 0.5 | $2.99 |  | $2.99 | $0.08
Pushbutton Switch | Control Box | $2.99 | 1 | $2.99 |  | $2.99 | $0.08
I1N4454 Diodes | Power Board | $0.60 | 5 | $3.00 |  | $3.00 | $0.08
Blue LED Module (10 of 20pack) | Audio System | $6.99 | 0.5 | $3.50 |  | $3.50 | $0.08
Red LED Module (10 of 20pack) | Audio System | $6.99 | 0.5 | $3.50 |  | $3.50 | $0.08
3" Branch Adapter | Appearance | $3.48 | 1 | $3.48 | 1 | $3.77 | $0.08
3.3V regulator | Control Box | $3.79 | 1 | $3.79 |  | $3.79 | $0.08
3" to 4" adapter PVC | Appearance | $3.74 | 1 | $3.74 | 1 | $4.05 | $0.08
DFRobot MP3 Module | Audio System | $4.22 | 1 | $4.22 |  | $4.22 | $0.08
Barrel Power Connector | Audio System | $3.99 | 1 | $3.99 | 1 | $4.32 | $0.08
Mini Pushbutton Switch (power) | Control Box | $3.99 | 1 | $3.99 | 1 | $4.32 | $0.08
Propane Tanks (modified, painted) | BB Cannon | $3.99 | 1 | $3.99 | 1 | $4.32 | $0.08
Ground Dist Block | Power Board, Control Box | $4.47 | 1 | $4.47 |  | $4.47 | $0.08
12V Buzzer | Control Box | $4.72 | 1 | $4.72 |  | $4.72 | $0.08
Bussman Low Amp Fuse Pack | Control Box | $4.39 | 1 | $4.39 | 1 | $4.75 | $0.08
1/8 Audio Jack | Audio System | $4.49 | 1 | $4.49 | 1 | $4.86 | $0.08
3D Printed LED rings | Audio System | $2.50 | 2 | $5.00 |  | $5.00 | $0.08
Cat5 Connector and Plug | Power Board | $5.00 | 1 | $5.00 |  | $5.00 | $0.08
Staineless Steel Front Cover | Appearance | $5.00 | 1 | $5.00 |  | $5.00 | $0.08
Black Ornate Screen Aluminum Milled Sheet (end covers) | Power Board | $18.98 | 0.25 | $4.75 | 1 | $5.14 | $0.08
Misc Connection Wire | Control Box, Power Board | $5.00 | 1 | $5.00 | 1 | $5.41 | $0.08
32GB SD Card | Audio System | $5.45 | 1 | $5.45 |  | $5.45 | $0.08
Colored Vinyl Tape | Appearance | $5.67 | 1 | $5.67 |  | $5.67 | $0.08
3" right angle PVC | Appearance | $2.65 | 2 | $5.30 | 1 | $5.74 | $0.08
Resistors (10k*2, 220*2, 1m) | Control Box | $0.25 | 23 | $5.75 |  | $5.75 | $0.08
Nuts & Bolts | Misc | $5.90 | 1 | $5.90 |  | $5.90 | $0.08
4" PVC end cap | Appearance, BB Shower | $2.10 | 3 | $6.30 | 1 | $6.82 | $0.08
1.2 NPT to 1/2 barb | BB Shower | $3.19 | 2 | $6.38 | 1 | $6.91 | $0.08
Plexiglass sheet (Comp cover, CPU cover, LCD Cover) | BB Cannon, Control Box | $7.99 | 0.8 | $6.39 | 1 | $6.92 | $0.08
4 Fuse Power Dist Block | Control Box | $6.99 | 1 | $6.99 |  | $6.99 | $0.08
Vinyl Flex Pipe | BB Cannon | $6.60 | 1 | $6.60 | 1 | $7.14 | $0.08
Steel Band Clamp 4" | Appearance, BB Shower, Power Board | $1.68 | 4 | $6.72 | 1 | $7.27 | $0.08
Screw Connectors | Control Box | $1.50 | 5 | $7.50 |  | $7.50 | $0.08
IRFZ34 MOSFET N channel | Control Box | $0.88 | 9 | $7.94 |  | $7.94 | $0.08
LCD 4x20 + I2C interface | Control Box | $8.55 | 1 | $8.55 |  | $8.55 | $0.08
100PSI Safety Valve | BB Shower | $8.61 | 1 | $8.61 |  | $8.61 | $0.08
6 Fuse Power Dist Block | Power Board | $8.69 | 1 | $8.69 |  | $8.69 | $0.08
1/8 to 1/4 NPT adapter | BB Shower | $8.90 | 1 | $8.90 |  | $8.90 | $0.08
HP JetDirect Cards (2 modified for disable) | Control Box | $3.00 | 3 | $9.00 |  | $9.00 | $0.08
4" x 10' PVC DVW tube | Appearance | $12.17 | 0.7 | $8.52 | 1 | $9.22 | $0.08
10x2W Audio Amp | Audio System | $9.88 | 1 | $9.88 |  | $9.88 | $0.08
Control Box | Control Box | $10.00 | 1 | $10.00 |  | $10.00 | $0.08
Adjustable NC Pressure Switch | BB Shower | $10.49 | 1 | $10.49 |  | $10.49 | $0.08
Smart SLA Charger | Control Box | $10.99 | 1 | $10.99 |  | $10.99 | $0.08
Landscape Drain Heads | Audio System | $5.38 | 2 | $10.76 | 1 | $11.65 | $0.08
3" x 10' PVC DVW tube | Appearance, BB Shower | $10.78 | 1 | $10.78 | 1 | $11.67 | $0.08
12VDC Siren | Audio System | $11.77 | 1 | $11.77 |  | $11.77 | $0.08
30A 12VDC Relay | Control Box, Power Board | $2.50 | 5 | $12.50 |  | $12.50 | $0.08
12V Slime Brand Car Compressor | BB Shower | $12.28 | 1 | $12.28 | 1 | $13.29 | $0.08
Sprinkler Valve | BB Cannon | $12.97 | 1 | $12.97 | 1 | $14.04 | $0.08
Propane to 1/2NPT adapter | BB Shower | $7.58 | 2 | $15.16 |  | $15.16 | $0.08
Pyle PLMR51B Speakers | Audio System | $20.39 | 1 | $20.39 |  | $20.39 | $0.08
12v SLA 7Ahr | Power Board | $19.99 | 1 | $19.99 | 1 | $21.64 | $0.08
Teensy 3.2 LC | Control Box | $19.99 | 1 | $19.99 | 1 | $21.64 | $0.08
Steel Band Clamp 6" | Appearance, BB Shower | $4.36 | 5 | $21.80 | 1 | $23.60 | $0.08
Dual Horn Air Horn | Audio System | $35.00 | 1 | $35.00 | 1 | $37.89 | $0.08
 |  |  |  | $512.68 |  | $532.48

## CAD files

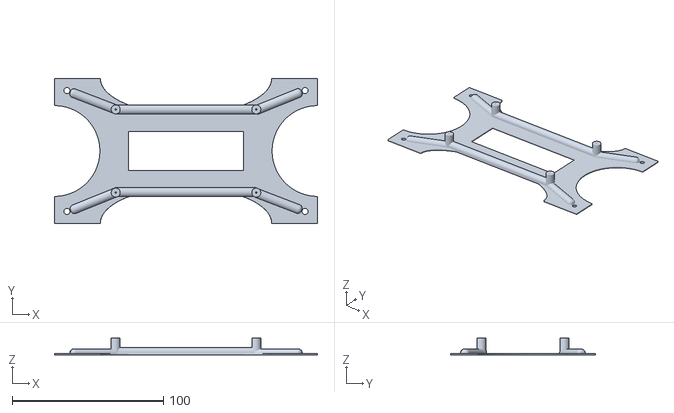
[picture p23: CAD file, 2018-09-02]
Huge Prop Bomb LCD.stl
174.0 x 96.0 x 11.0

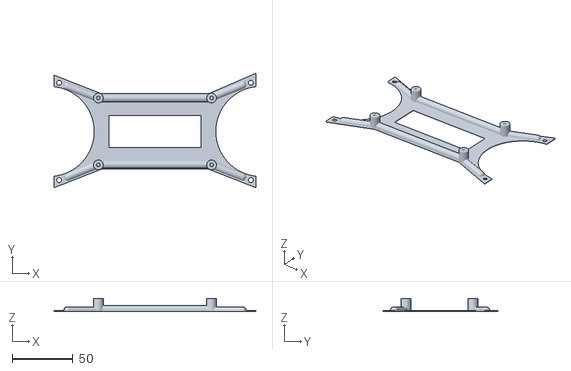
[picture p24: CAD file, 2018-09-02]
BB LCD b.stl
166.0 x 94.2 x 11.0

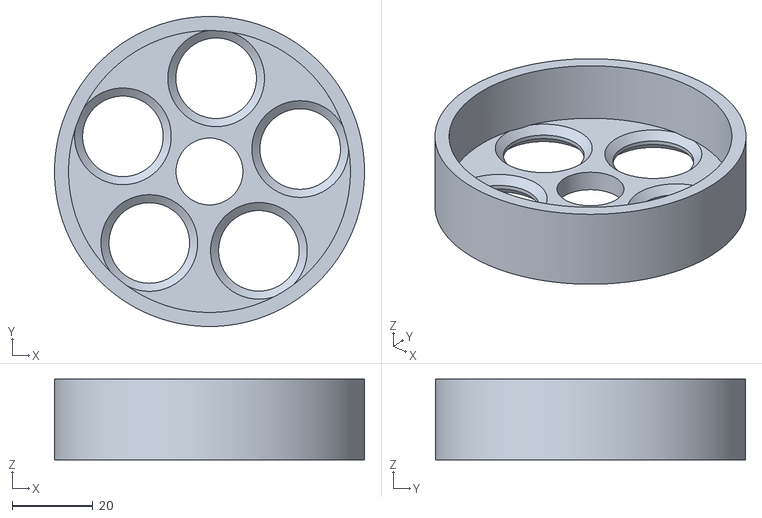
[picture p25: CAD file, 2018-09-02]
BB Shower Support.stl
77.0 x 77.0 x 20.0

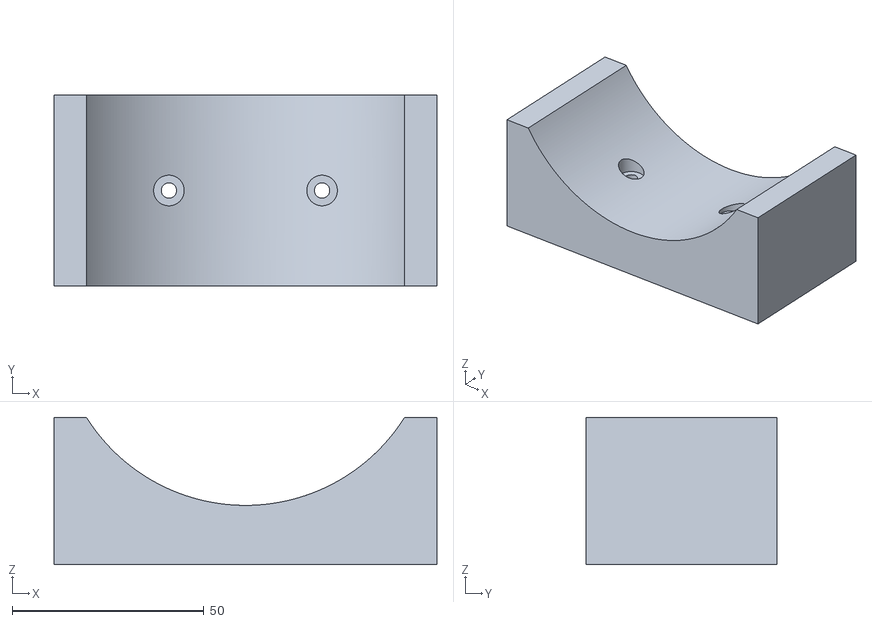
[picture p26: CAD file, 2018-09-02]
Huge Prop Bomb Tank.stl
100.0 x 50.0 x 38.5

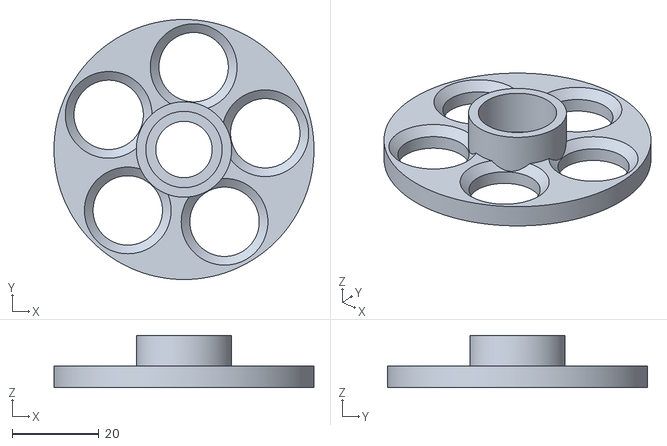
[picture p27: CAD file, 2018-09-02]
BB Shower Base.stl
60.0 x 60.0 x 12.0

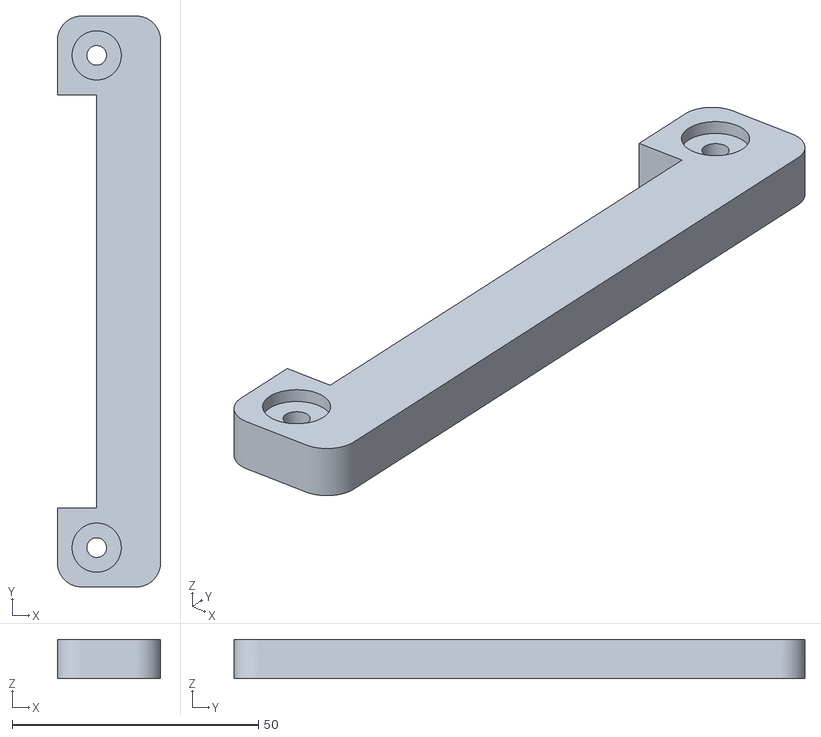
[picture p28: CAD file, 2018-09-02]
Huge Prop Bomb Board.stl
21.0 x 116.0 x 8.00

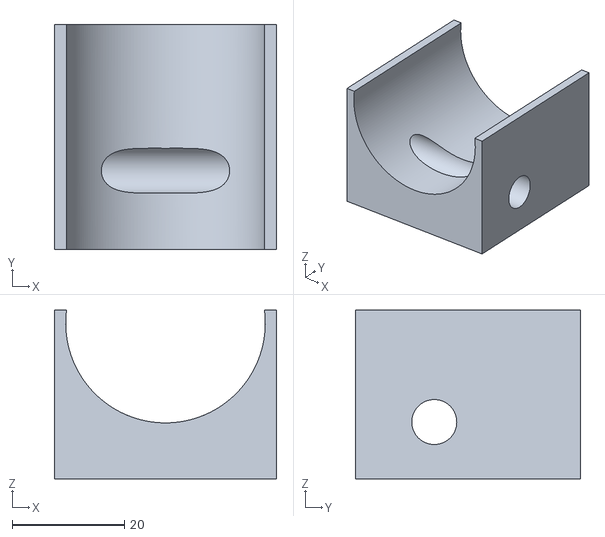
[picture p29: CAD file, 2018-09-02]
BB Shower Pump.stl
39.5 x 40.0 x 30.0

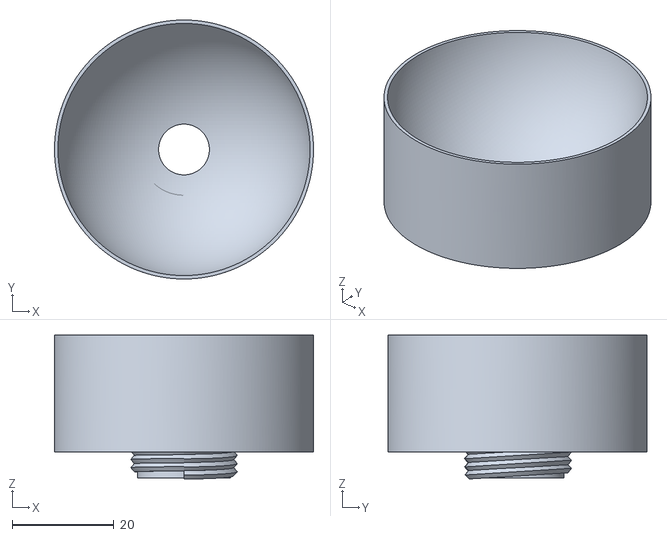
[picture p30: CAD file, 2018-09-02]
BB Shower Cup.stl
51.0 x 51.0 x 28.4

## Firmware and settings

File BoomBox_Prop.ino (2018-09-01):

 /* D14 HUGE Bomb Prop Code v1.1
   Hardware has:
   1. 2 Red, 2 Blue, 2 white LED Strobes. (right and left) (6 DO)
   2. Air Horns switched by relay. (not powered by case) (1DO)
   3. LCD (I2C interface) 4x20 Blue.
   4. 4x3 Keypad (traditional matrix interface).
   5. Buzzer.
   6. Large Red Button.
   7. Siren.
   8. Compressor.
   9. Purge Valve.
   10. A3 input with voltage divider to measure batt voltage.
   11. Smoke Output.
   12. Can Sense Input (reed switch).
   13. MP3 Serial I/O.

   MODES:
   Pressing red button enters program mode during initialization. Battery voltaqe displayed during power up.
   1. Simple Countdown - Unit counts down and explodes unless red cancel button is pressed. pressing red button restarts.
   2. PIN-Countdown - A PIN (2-9 digits) starts countdown time and pauses. EOD Guess allows guessing PIN.
   3. Repeating Countdown - Unit counts down and explodes unless red reset button is pressed. Reset restarts countdown.
   Program Mode - Set game options and game modes. * exits programming and starts game.

   EOD Mode:
   1. EOD-Guess - Only for PIN countdown. Wrong PIN wont trigger, it gives you a Too High or Too Low response. * gives a +/- 200 number range hint.
   
   EEPROM Structure:
   0 - Default game mode.
   1 - Strobe during countdown(Bit 1), Beep during countdown (Bit 2), EOD Wire Guess Mode (Bit 3), BB Cannon Mode (Bit 4), Card Sense (Bit 5),
     Two Min Warning (Bit 6), Pre Countdown Beep (Bit 7), Can Sense (Bit 8)
   2 - Alert Duration (default 20s).
   3-4 - Countdown time (Seconds, 0-64000)
   5-8 - PIN (long)
   9 - Juke Box MP3 delay in minutes.
   10 - Main volume (1-30)
   11 - Two Minute Countdown Song (0=none, 1-254 for alternate)
*/
#include <EEPROM.h>
#include <Keypad.h>
#include <LiquidCrystal_I2C.h>
#include <DFPlayer_Mini_Mp3.h>
# define HWSERIAL Serial1
// RX1,RX2 - MP3 Serial DIO
const byte sirenPIN = 2; // HIGH = Siren on.
const byte compPIN = 3; // HIGH = Compressor powered.
const byte valvePIN = 4; // HIGH = Purge air.
const byte buzzPIN = 5; // HIGH = Piezo Buzzer on.
const byte hornPIN = 17; // HIGH = Ext relay on.
const byte brbPIN = 20; // LOW = Big Red Button pressed.
const byte cardPIN = 24; // LOW = Card inserted.
const byte canPIN = 22; // LOW = Canister inserted.
byte rowPins[4] = {6,7,8,9}; // connect to the row pinouts of the keypad
byte colPins[3] = {10,12,11}; // connect to the column pinouts of the keypad
char keys[4][3] = {
  {'1','2','3'},
  {'4','5','6'},
  {'7','8','9'},
  {'*','0','#'}
};
const byte ledRedPIN = 13; // HIGH = Red LEDs on.
const byte ledBluePIN = 14; // HIGH = Blue LEDs on.
// SDA0, SCL0 - LCD I2C DIO (Pins 18,19)
const byte ledWhitePIN = 15; // HIGH = White LEDs on.
//const byte smokePIN = 16; // HIGH = White LEDs on. Not Used Currently.
const byte voltPIN = 9; // Voltage Measurement analong PIN. (Pin 23)
byte volMP3 = 23; // Volume of MP3 player, 0-30.
byte currMP3 = 100; // Current MP3 track.
byte mp3Top = 117; // Last MP3 file number.
byte twoMinMP3 = 36; // Song number to play on 2 minute countdown. 0=none.
char key;
int cdPeriod = 1200; // Number of seconds for countdown. 64000 - 17 h max
long lngPIN = 0; // The 1 to 9 digit PIN code needed for the game.
unsigned long timeOut = 0; // millis when we reach end of some important countdown.
unsigned long menuRefresh = 0; // Controls refresh rate for menu.
String lcdLine1 = ""; // Holds current LCD Line 1 text.
String lcdLine2 = ""; // Holds current LCD Line 2 text.
String lcdLine3 = ""; // Holds current LCD Line 3 text.
String lcdLine4 = ""; // Holds current LCD Line 4 text.
String gameNames[4] = {"Countdown","PIN Countdown","Rpt-Countdown","Can-Countdown"};
Keypad keypad = Keypad( makeKeymap(keys), rowPins, colPins, 4, 3 );
LiquidCrystal_I2C lcd(0x3F, 2, 1, 0, 4, 5, 6, 7, 3, POSITIVE);  // Set the LCD I2C address, SDA0-18, SCL0-19
  
// Game Play Variables
bool cdBeep = false; // Countdown Beep enabled.
bool cdStrobe = false; // Countdown Strobe enabled.
bool canSense = false; // Canister sensing is not used when false.
bool bbCanon = false; // True if BB Cannon is enabled.
bool preCDBeep = false; // Beeps to help locate bomb on field before countdown or interaction starts.
bool twoMin = false; // True if 2 minute air raid warning is enabled.
bool eodMode = false; // Global to indicate EOD Guess Mode is active.
bool cardSense = false; // Global to indicate card presence sense is active.
bool played = false; // Indicates some MP3 file has already been played.
bool jukeMode = true; // if True, play audio, if false, play sys info files.
bool blnWhite = false; // Which LED is/was flashed, used to alternate flashes.
bool firstRun = true; // Global used to indicate first run thru a subroutine.
bool gameOn = true; // GameOn or Prog mode, or neither (device disabled). Default startup goes direct into a game.
byte x = 5; // Used for Canister Mode timing loops.
byte gameMode = 1; // Of the games we can play, this is the current mode.
byte lastgameMode = 1; // Stores the game mode for juke box mode to return to.
byte alertPeriod = 20; // 20s default alert period when triggered.
byte gameStep = 0; // What step in the game mode we are in. Games have different steps or sequences.
byte pinFail = 0; // Counts number of PIN entry failures.
byte songPeriod = 15; // Minutes between songs when idle. 0 = disabled.
long enteredPIN = 0; // What PIN code was entered by player.
unsigned long songTimer = 0; // how many millis till the next song.
unsigned long eodTimeout = 0; // Contains millis for end of eod bypass period (less than main countdown, 2 minutes max).
unsigned long nextCheck = 0; // How many millis till clock needs updating.
unsigned long nextEODCheck = 0; // How many millis till EOD clock needs updating (2 minute countdown vs main countdown clock).

// Programming Variables
byte configByte = 0; // Used to read config from EEPROM and in program mode sub.
bool progMode = false; // Game mode or Prog mode, or neither (device disabled).
bool optionShown = false; // Programming - did we show the current option state already?
bool progSelected = false; // Programming - did we choose what to change?
byte progMenu = 0; // What Program Option we should show.

void setup() {
  int voltRaw = 0; // input value for Analog voltage measurement.
  float pinVoltage = 0; // holds calc voltage for Analog voltage measurement.
  byte eepromHigh = 0; // Used to parse EEPROM reads.
  byte eepromLow = 0; // Used to parse EEPROM reads.

  // Set PinModes.
  pinMode(ledRedPIN, OUTPUT);
  digitalWrite(ledRedPIN,LOW);
  pinMode(ledBluePIN, OUTPUT);
  digitalWrite(ledBluePIN,LOW);
  pinMode(ledWhitePIN, OUTPUT);
  digitalWrite(ledWhitePIN,LOW);
  pinMode(hornPIN, OUTPUT);
  digitalWrite(hornPIN,LOW);
  pinMode(sirenPIN, OUTPUT);
  digitalWrite(sirenPIN,LOW);
  pinMode(buzzPIN, OUTPUT);
  digitalWrite(buzzPIN,LOW);
  pinMode(compPIN, OUTPUT);
  digitalWrite(compPIN,LOW);
  pinMode(valvePIN, OUTPUT);
  digitalWrite(valvePIN,LOW);
//  pinMode(smokePIN, OUTPUT);
//  digitalWrite(smokePIN,LOW);
  pinMode(voltPIN,INPUT); // Analog A9 voltage input
  pinMode(brbPIN, INPUT_PULLUP);
  pinMode(cardPIN, INPUT_PULLUP);
  pinMode(canPIN, INPUT_PULLUP);

//  Serial.begin(9600);
//  Serial.println("Starting...");    

  // Byte 0 - Get Default game mode from EEPROM
  gameMode = EEPROM.read(0);
  if(gameMode < 1 || gameMode > 4) {
    EEPROM.write(0,1);
    gameMode = 1;
  }
  // Byte 1 Get Config Byte from EEPROM
  configByte = EEPROM.read(1);
  if(configByte > 255) { // If its invalid, clear it.
    EEPROM.write(1,0);
    configByte = 0; 
  }
  if(configByte & 1) cdStrobe = true;
  if(configByte & 2) cdBeep = true;
  if(configByte & 4) eodMode = true;
  if(configByte & 8) bbCanon = true;
  if(configByte & 16) cardSense = true;
  if(configByte & 32) twoMin = true;  
  if(configByte & 64) preCDBeep = true;  
  if(configByte & 128) canSense = true;  
  // Byte 2 Get explosion Duration from EEPROM
  alertPeriod = EEPROM.read(2);
  if(alertPeriod < 1 || alertPeriod > 240) { // If its invalid, set to default.
    EEPROM.write(2,20);
    alertPeriod = 20;
  }
  // Byte 3,4 Get Countdown time (Seconds, 0-64000) from EEPROM
  eepromHigh = EEPROM.read(3);
  eepromLow = EEPROM.read(4);
  cdPeriod = word(eepromHigh,eepromLow);
  if(cdPeriod > 64000 || cdPeriod < 1) { // If its invalid, set to default.
    EEPROM.write(3,4);
    EEPROM.write(4,176);
    cdPeriod = 1200; // 1200 seconds
  }
  // Byte 5-8 Get PIN from EEPROM
  lngPIN = EEPROMReadLong(5);
  if(lngPIN < 1 || lngPIN > 999999999) { // If its invalid, set to default.
    lngPIN = 1234;
    EEPROMWriteLong(5,lngPIN);
  }
  // Byte 9 - Get MP3 Song delay in minutes from EEPROM
  songPeriod = EEPROM.read(9);
  if(songPeriod > 60) {
    EEPROM.write(9,15);
    songPeriod = 15;
  }
  // Byte 10 - Get main volume from EEPROM
  volMP3 = EEPROM.read(10);
  if(volMP3 > 30) {
    EEPROM.write(10,24);
    volMP3 = 24;
  }
  // Byte 11 - Get MP3 Song for 2 minute countdown from EEPROM
  twoMinMP3 = EEPROM.read(11);
  if(twoMinMP3 > mp3Top) {
    EEPROM.write(11,36);
    twoMinMP3 = 36;
  }
  randomSeed(analogRead(7));
  lcd.begin(20,4);   // Initialize the lcd for 16 chars 2 lines, turn on backlight
  lcd.backlight();
  HWSERIAL.begin(9600);
  mp3_set_serial (HWSERIAL); //set Serial for DFPlayer-mini mp3 module 
  delay(1000);
  mp3_set_volume (volMP3);
  mp3_set_EQ(0); // Specify EQ 0/1/2/3/4/5  Normal/Pop/Rock/Jazz/Classic/Bass
  digitalWrite(ledRedPIN,HIGH);
  voltRaw = analogRead(voltPIN);
  pinVoltage = voltRaw * 0.0212;       //  Calculate the voltage on the A/D pin 4.7k/2.2k = 0.015 multiplier
  if (pinVoltage < 12.0) {
    if (pinVoltage < 11.3) {
      mp3_play (3); //play Critical Battery MP3
    } else {
      mp3_play (2); //play Low Battery MP3
    }
  } else {
    mp3_play (23); //play Startup MP3
  }
  timeOut = millis() + 6000;
  lcdLine1=F("D14 Airsoft BoomBox");
  lcdLine2=F("Press the red button");
  lcdLine3=F("to program.");
  lcdLine4=F("FW Version 1.1
  ");
  while(millis() < timeOut){ // For 6 seconds after power up, wait for BRB press.
    if ((timeOut - 4000) < millis()) {
        digitalWrite(ledRedPIN,LOW);
        delay(20);
        digitalWrite(ledRedPIN,HIGH);
        delay(20);
    }
    if ((timeOut - 2200) < millis()) {
        lcdLine4 = "Battery: " + String(pinVoltage);
        if (pinVoltage < 12) {
          lcdLine4 = F("LOW BATTERY!");
        }
        digitalWrite(ledBluePIN,LOW);
        delay(20);
        digitalWrite(ledBluePIN,HIGH);
        delay(20);
    }
    if((digitalRead(brbPIN) == LOW) && ((timeOut - 1000) < millis()) ) { // If BRB is pressed, enter program mode.
      lcdLine4=F("Entering prog mode.");
      progMode = true;
      gameOn = false;
      timeOut = millis();
      break;
    }
    if ((timeOut - 1300) < millis()) {
        digitalWrite(ledWhitePIN,LOW);
        delay(20);
        digitalWrite(ledWhitePIN,HIGH);
        delay(20);
    }
    if (menuRefresh < millis()) {
      writeLCD(0);
      menuRefresh = millis() + 1000;
    }
  }
  digitalWrite(ledWhitePIN,LOW);
  digitalWrite(ledRedPIN,LOW);
  digitalWrite(ledBluePIN,LOW);
  clearLCD();
}

void loop() {
  if(progMode) programMode();
  if(gameOn) {
    if (firstRun) {
      clearLCD();
      key = keypad.getKey();
      if (key != NO_KEY) { // Check for key and process.
        if (key == '#') {
          lastgameMode = gameMode;
          gameMode = 5;
          // Set up the LCD
          lcdLine1 = F("1=Music/Info        ");
          lcdLine2 = F("4=Prev        6=Next");
          lcdLine3 = F("7=Vol+        9=Stop");
          lcdLine4 = F("*=Vol-        #=EXIT");
          writeLCD(0);
          currMP3 = 1;
        }
      }
      if (!played) {
        played = true;
        switch (gameMode) {
          case 1:
            currMP3 = 9;
            lcdLine1 = F("Simple Countdown.");
          break;
          case 2:
            currMP3 = 6;
            lcdLine1 = F("PIN Locked Countdown");
          break;
          case 3:
            currMP3 = 18;
            lcdLine1 = F("Repeating Countdown");
          break;
          case 4:
            currMP3 = 12;
            lcdLine1 = F("Canister Countdown");
          break;
          case 5:
            currMP3 = 5;
            lcdLine1 = F("Jukebox Mode");
          break;
        }
        writeLCD(0);
        mp3_set_volume (volMP3);
        mp3_play(currMP3);
        if ((bbCanon) && (gameMode != 5)) {
          lcdLine2 = F("BB Cannon is ACTIVE!");
          lcdLine3 = "";
          lcdLine4 = F("USE EYE PROTECTION!");
        }
        writeLCD(4000);
        if ((bbCanon) && (gameMode != 5)) {
          mp3_set_volume (23);
          digitalWrite(ledRedPIN,HIGH); // Red LED On
          mp3_play(14);
          delay(11000);
          mp3_set_volume (volMP3);
          digitalWrite(ledRedPIN,LOW); // Red LED On
          clearLCD();
        }
      }
      firstRun = false;
      timeOut = millis() + (long(cdPeriod) * 1000);
      nextCheck = millis() + 1000;
      gameStep = 0;
      played = false;
    } else {
      switch (gameMode) {
        case 1: //Simple countdown
          simpleCD(false);
          break;
        case 2: //PIN countdown
          pinCountdown();
          break;
        case 3: //Repeating countdown
          simpleCD(true);
          break;
        case 4: //Canister countdown
          canCD();
          break;
        case 5: //Jukebox
          jukeBox();
          break;
      }
    }
  }
  if ((!gameOn) && (!progMode) && (songPeriod != 0)) {
    if (songTimer == 0) {
      songTimer = millis() + (songPeriod * 60000);
    }
    if (songTimer < millis()) {
      // Time for a song!
      int rndSong = random(100,mp3Top);
      mp3_set_volume (volMP3);
      mp3_play (rndSong); 
      songTimer = millis() + (songPeriod * 60000);
      lcdLine3 = F("Random MP3 play mode");
      lcdLine4 = F("Press button to stop");
      writeLCD(0);
    }
    if (digitalRead(brbPIN) == LOW) {
      mp3_stop();
    }
    key = keypad.getKey();
    if (key != NO_KEY) { // Check for key and process.
      switch (key) {
       case '4':
          // Next.
          mp3_next();
          break;
       case '7':
          // Vol Up.
          if (volMP3 > 29) {
            volMP3 = 30;
          } else {
            volMP3 ++;  
          }
          mp3_set_volume (volMP3);
          break;
       case '*':
          // Vol Down.
          if (volMP3 < 1) {
            volMP3 = 0;
          } else {
            volMP3 --;
          }
          mp3_set_volume (volMP3);
          break;      
        }
     delay(200);
    }
  }
}

void jukeBox() {
  // Music play form internal SD card.
  if (!played) {
    played = true;
    mp3_play (5); // Play jukebox MP3.
    delay(3000);
  }
  // Check for input
  key = keypad.getKey();
  if (key != NO_KEY) { // Check for key and process.
    byte mp3Upper = mp3Top; 
    byte mp3Lower = 100; 
    String tmpString = "";
    // Act on input.
    if (jukeMode) {
      mp3Upper = mp3Top;
      mp3Lower = 100;
    } else {
      mp3Upper = 36;
      mp3Lower = 1;
    }
    switch (key) {
       case NO_KEY:
          break;
       case '1':
          if (jukeMode) {
            jukeMode = false;
            currMP3 = 1;
          } else {
            jukeMode = true;
            currMP3 = 100;
          }
          break;
       case '2':
          mp3_set_EQ(3);
          break;
       case '5':
          mp3_set_EQ(2);
          break;
       case '8':
          mp3_set_EQ(4);
          break;
       case '0':
          mp3_set_EQ(0);
          break;
       case '4':
          // Back one song.
          if (currMP3 < (mp3Lower+1)) {
            currMP3 = mp3Lower;
          } else {
            currMP3 --;  
          }
          tmpString = String(currMP3);
          lcdLine1 = "1=Music/Info     " + tmpString;
          writeLCD(0);
          mp3_play(currMP3);
          break;
       case '6':
          // Next Song.
          if (currMP3 > (mp3Upper-1)) {
            currMP3 = mp3Upper;
          } else {
            currMP3 ++;  
          }
          tmpString = String(currMP3);
          lcdLine1 = "1=Music/Info     " + tmpString;
          writeLCD(0);
          mp3_play(currMP3);
          break;
       case '7':
          // Vol Up.
          if (volMP3 > 29) {
            volMP3 = 30;
          } else {
            volMP3 ++;  
          }
          mp3_set_volume (volMP3);
          break;
       case '9':
          // Stop.
          mp3_stop();
          break;
       case '*':
          // Vol Down.
          if (volMP3 < 1) {
            volMP3 = 0;
          } else {
            volMP3 --;
          }
          mp3_set_volume (volMP3);
          break;
       case '#':
          // Exit.
          mp3_stop();
          gameMode = lastgameMode;
          firstRun = true;
          played = false;
          break;
    }     
  }
}

void pinCountdown() {
  if (gameStep == 0) {
    // Initialize and ask for PIN
    clearLCD();
    digitalWrite(compPIN,LOW); // turn off compressor.
    lcdLine1 = F("PIN Locked Countdown");
    if ((canSense) && (digitalRead(canPIN) == LOW)) {
      // Can Sense in PIN game means it disables system. So we DONT want to start with it present.
      lcdLine2 = F("Can MUST BE REMOVED");
      writeLCD(0);
      beep(500);
      while (digitalRead(canPIN) == LOW) {
        lcdLine3 = F("Waiting...");
        writeLCD(500);
      }
    }
    if ((cardSense) && (digitalRead(cardPIN) == LOW)) {
      // Card Sense in PIN game means it disables system. So we DONT want to start with it present.
      lcdLine2 = F("Card MUST BE REMOVED");
      writeLCD(0);
      beep(500);
      mp3_play(31); // play card error.
      while (digitalRead(cardPIN) == LOW) {
        lcdLine3 = F("Waiting...");
        writeLCD(500);
      }
      lcdLine2 = "Enter PIN to start:";
      lcdLine3 = "";
    } else {
      lcdLine2 = F("Enter PIN to start:");
    }
    writeLCD(0);
    if (!played) {
      played = true;
      mp3_play (8); // Play enter PIN MP3.
      nextCheck = millis() + 10000;
      if (preCDBeep) {
        lcdLine3 = F("Locator Beep ON");
        writeLCD(0);
      }
    }
    enteredPIN = getLong(1,999999999, 3);
    if (enteredPIN == lngPIN) {
      gameStep = 1;
      preCDBeep = false;
      timeOut = millis() + (long(cdPeriod) * 1000);
      nextCheck = millis() + 10;
      lcdLine2 = F("Enter PIN to pause:");
      lcdLine3 = "";
      enteredPIN = 0;
    } else {
      lcdLine3 = F("INCORRECT PIN!");
      writeLCD(0);
      digitalWrite(ledRedPIN,HIGH);
      digitalWrite(sirenPIN,HIGH); // Siren On
      delay(200);
      digitalWrite(sirenPIN,LOW); // Siren Off
      digitalWrite(ledRedPIN,LOW);
      delay(1000);
    }
  }
  if (gameStep == 1) { // Countdown, check for pin or if EOD is allowed.
    played = false;
    if (nextCheck < millis() ) {
      nextCheck = checkTimer(timeOut);
      altStrobe();
    }
    // Check for disable card or can
    delay(2);
    if ((cardSense) && (digitalRead(cardPIN) == LOW)) {
       disableEnd();
    }
    if ((canSense) && (digitalRead(canPIN) == LOW)) {
       disableEnd();
    }
    key = keypad.getKey();
    if (key != NO_KEY) { // Check for key and process.
      switch (key) {
         case NO_KEY:
            break;
         case '0': case '1': case '2': case '3': case '4':
         case '5': case '6': case '7': case '8': case '9':
            beep(30);
            enteredPIN = enteredPIN * 10 + (key - '0');
            lcdLine3 = String(enteredPIN);
            writeLCD(0);
            break;
         case '*':
            beep(30);
            if (eodMode && enteredPIN == 0) {
              lcdLine3 = String(lngPIN+random(200)) + "-" + String(lngPIN-random(200));
            } else {
              lcdLine3 = "";
            }
            writeLCD(0);
            enteredPIN = 0;
            break;
         case '#':
            // CHeck for valid PIN
            if (enteredPIN == lngPIN) {
              gameStep = 2;
              cdPeriod = (timeOut - millis()) / 1000; // Set new cdPeriod to remaining time.
            } else {
              if (eodMode) {
                if (enteredPIN > lngPIN ) {
                  lcdLine3 = F("PIN too high.");
                } else {
                  lcdLine3 = F("PIN too low.");
                }
              } else {
                lcdLine3 = F("INCORRECT PIN!");
                writeLCD(0);
                pinFail ++;
                if (pinFail > 2) {
                  speedDet();
                }
              }
              digitalWrite(ledRedPIN,HIGH);
              digitalWrite(sirenPIN,HIGH); // Siren On
              delay(200);
              digitalWrite(sirenPIN,LOW); // Siren Off
              digitalWrite(ledRedPIN,LOW);
              delay(1000);
              enteredPIN = 0;
            }
            break;      
      }
    }
    if (nextCheck == 0) { // Time to detonate.
      detonate();
    }
  }
  if (gameStep == 2) {
    // Countdown paused.
    digitalWrite(compPIN,LOW); // turn off compressor.
    lcdLine2 = F("Enter PIN to restart");
    lcdLine3 = "";
    writeLCD(0);
    digitalWrite(ledWhitePIN,LOW);
    enteredPIN = getLong(1,999999999, 3);
    if (enteredPIN == lngPIN) {
      gameStep = 1;
      pinFail = 0;
      timeOut = millis() + (long(cdPeriod) * 1000);
      nextCheck = millis() + 10;
      lcdLine2 = F("Enter PIN to pause:");
      lcdLine3 = "";
      enteredPIN = 0;
    } else {
      lcdLine2 = F("INCORRECT PIN.");
      writeLCD(0);
      digitalWrite(ledRedPIN,HIGH);
      digitalWrite(sirenPIN,HIGH); // Siren On
      delay(200);
      digitalWrite(sirenPIN,LOW); // Siren Off
      digitalWrite(ledRedPIN,LOW);
      delay(1000);
    }
  }
}
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

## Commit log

2018-09-01 Project Images
    This is my implementation of the "BoomBox" which was pieced together using found parts and off the shelf hardware. 2x4 wood and PVC waste pipe make up the make components with a control box made from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
2018-09-01 BoomBox arduino IDE code file.
    The project uses a teensy module, mp3 module, and several other components, but this is the main code for the teensy that runs the system.
2018-09-02 BoomBox Prop BOM parts cost sheet.
    The expenses incurred for building the prop device. Circa 2016-2017. Most parts sourced from Home Depot, Banggood or Ebay vendors.
    [BoomBox Prop Expenses.ods]
2018-09-02 "Make the Cut" template for logos used on the BoomBox
    Template file for cutter used to make vinyl stickers for the device.
2018-09-02 Owner and Instruction Manual for BoomBox
    Usage, maintenance, and construction guide including schematics and other relevant information. Note that this manual is tailored for the company I created the prop device for, D14 Airsoft. Do not re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
2018-09-02 3D Printer files
    I use 123D from autocad.. however its an obsolete app now. I believe you can convert them in fusion360 however.
    [BB LCD b.stl, BB Shower Base.stl, BB Shower Cup.stl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]
2018-09-02 More prop documentation
    The prop went thru several changes in the code, so the manuals are hit and miss.. but fairly accurate. This upload includes a video of the prop in operation in the early 'release' phase..
